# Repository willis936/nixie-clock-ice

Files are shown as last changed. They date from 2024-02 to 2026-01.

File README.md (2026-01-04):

# nixie-clock-ice

 Hardware and software source for a GPS nixie tube clock with delay correction.

Uses a PICO-iCE v3 FPGA + MCU module.

 - Raspberry Pi RP2040 processor
 - Lattice UltraPlus ICE40UP5K FPGA with 5.3k LUTs, 1Mb SPRAM, 120Kb DPRAM, 8 Multipliers

# Building

## Cloning

Clone with git CLI of the native OS (Windows if running WSL).
This avoids checkout conflicts.
Github desktop recursively inits submodules, which breaks on Windows due to path length limitations.

```
git clone https://github.com/willis936/nixie-clock-ice.git
```

Once cloned cd to `software/lib` and run these commands to initialize the submodules:

```
git -C pico-ice-sdk submodule update --init
git -C pico-sdk submodule update --init lib/tinyusb
```

Run these commands until the output stops changing.  Running them once is likely not sufficient.

See the "Using the SDK" section of the pico iCE "Getting Started" page.

https://pico-ice.tinyvision.ai/md_getting_started.html

## MCU

Follow the pico ice Getting Started section.

Using Ubuntu WSL the apt version of cmake is currently not high enough.

Install an appropriate version like this:

https://www.linuxcapable.com/how-to-install-cmake-on-ubuntu-linux/

```
sudo apt update && sudo apt install build-essential checkinstall zlib1g-dev libssl-dev g++ gdb make ninja-build rsync zip gcc-arm-none-eabi
cd /usr/local/src
sudo wget https://github.com/Kitware/CMake/archive/refs/tags/v3.28.1.tar.gz
sudo tar -zxvf v3.28.1.tar.gz
sudo rm v3.28.1.tar.gz
cd CMake-3.28.1
sudo ./bootstrap
sudo make
sudo make install
```

For MacOS with homebrew installed:
```
brew install cmake gcc-arm-embedded zlib gdb make rsync zip
```

## FPGA

Make sure python 3.7+ is installed on WSL.

You may need to install pyenv, remove prior pip installations, and re-bootstrap.

https://gist.github.com/monkut/35c2ef098b871144b49f3f9979032cee

https://pip.pypa.io/en/stable/installation/

Install apio and oss CAD suite.

You may need to restart WSL in between the pip installation of the package and the package installation (last two commands).

```
sudo apt update && sudo apt install python3-pip yosys
pip install -U apio
apio install -a
```

For MacOS:
```
brew install yosys
pip3 install -U apio
```

Test project using the APIO guide here:

https://pico-ice.tinyvision.ai/md_programming_the_fpga.html

Use UF2 on WSL to convert the bin to UF2 then copy over CURRENT.UF2 on mounted USB drive pico ice.

https://github.com/tinyvision-ai-inc/uf2-utils/

```
cd /usr/local/src
sudo git clone https://github.com/tinyvision-ai-inc/uf2-utils.git
cd uf2-utils && sudo make install
```

# Enclosure development

If you want to modify the FreeCAD FCStd files you should configure zippey (located in `software/lib`) with these commands from git bash (Windows) or shell (linux) with the repo as pwd:

```
git config filter.zippey.smudge "$PWD/software/lib/zippey.py d"
git config filter.zippey.clean "$PWD/software/lib/zippey.py e"
```

Note that you need python 3 installed and added to path as `python` for the .FCStd files to properly compress on clone.

The enclosure was developed in FreeCAD 0.21.2 + Assembly3.  The Assembly3 plugin is needed to load the .FCStd file and modify the enclosure.

The enclosure starting point was generated by Protocase's template generator.

# Requirements

1. Display the time with 1 microsecond accuracy.
2. Display the time with 1 second precision.
3. Use nixie tubes to display the time.
4. Do not require or allow the user to manually set the time.
5. Display the time within 30 seconds of power on.
6. Use a single power entry.
7. Use a single radio receiver to establish local timebase.
8. Have a user-selectable mode for Daylight Savings Time (DST) checking.
9. Use longitude to estimate DST date range.
10. Have a user-selectable mode to force DST offset on (off when both this and DST check mode are off).
11. Use longitude to estimate timezone.
12. Have a user-selectable timezone offset.
13. Be able to use software to control nixie tube brightness.
14. Use an ambient light detector to automatically adjust nixie tube brightness.
15. Have a user-selectable manual brightness mode.
16. Use a potentiometer to set the brightness in manual brightness mode.
17. Run a nixie tube anti-poisoning routine once a day (cycle through all digits at high brightness for a minute).
18. Have a user-selectable mode to enable daily anti-poisoning routine
19. Have a user-selectable mode to force anti-poisoning routine on indefinitely.
20. Have a user-selectable 12-hour / 24-hour display mode.
21. Use a nixie tube decimal point to indicate AM/PM in 12-hour display mode.
22. Use a nixie tube decimal point to indicate that the radio receiver is locked.

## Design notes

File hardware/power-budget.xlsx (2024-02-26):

load | 5V (mA) | 3.3V (mA) | HV (mA) | 3.3V standby (mA)
nixies | 1680 |  | 33.6
RP2040 | 100 | 100
ice 40 UP5K | 50 | 50 |  | 0.25
MCP23008 | 1 | 1
LTR-329ALS-01 | 1.25 | 1.25
PX1125T | 100 | 100 |  | 0.54
ADC0820 | 7.5
Total | 1939.75 | 252.25 | 33.6 | 0.79

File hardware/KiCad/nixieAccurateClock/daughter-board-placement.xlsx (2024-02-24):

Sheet: clock
width | 152.4
edge | 2
width-working | 148.4
width-unit | 16
N-unit | 6
N-gaps | 5
width-spacing-total | 52.4
width-spacing-average | 10.48
N-gap-large | 2
width-gap-large | 13
width-gap-small | 8.8
origin | 15.875
width-mount | 4
offset-right | 6.08
offset-left | -5.92
clock | X
N1 | 158.195
N2 | 133.395
N3 | 104.395
N4 | 79.595
N5 | 50.595
N6 | 25.795

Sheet: precise
width | 152.4
edge | 2
width-working | 148.4
width-unit | 16
N-unit | 6
N-gaps | 5
width-spacing-total | 52.4
width-spacing-average | 10.48
N-gap-large | 1
width-gap-large | 19
width-gap-small | 8.35
width-mount | 4
offset-right | 11.25
offset-left | -0.75
precise | X
N1 | 137.15
N2 | 112.8
N3 | 88.45
N4 | 53.45
N5 | 29.1
N6 | 4.75

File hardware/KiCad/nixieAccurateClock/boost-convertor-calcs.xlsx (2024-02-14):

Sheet: HV supply
Calcs from Art of Electronics - 3rd Edition, Section 9.6.6.a Boost convertor equations (continuous-conduction mode)
Bourns SRR1280-100M
 | nominal |  | min | max
Iout | 0.5368421053 | A | 0.4421052632 | 1.414736842
Vin | 4.75 | V | 4.75 | 4.75
f | 100000 | Hz | 100000 | 100000
T | 1e-05 | s | 1e-05 | 1e-05
L | 1e-05 | H | 1e-05 | 1e-05
Iin | 0.002659279778 | A | 0.002659279778 | 0.005956786704
Iin-delta | 4.219117647 | A | 4.105357143 | 4.29875
Vout | 42.5 | V | 35 | 50
D(uty cycle) | 88.82% |  | 86.43% | 90.50%
Iout(min) | 0.2357742215 | A | 0.2785778061 | 0.204190625
Ic(out)-delta | 4.8033241 | A | 3.257617729 | 14.89196676
IL(pk) | 6.912882923 | A | 5.3102963 | 17.04134176
Lmin | 4.391872753e-06 | H | 6.301164662e-06 | 1.443311709e-06

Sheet: Nixie limiting
Vdrop | 145 | V
R | 27000 | Ohm
Imin | -0.0001851851852 | A
Inom | 0.0009259259259 | A
Imax | 0.002037037037 | A
Vres-min | -5 | V
Vres-nom | 25 | V
Vres-max | 55 | V
Pres-min | 0.0009259259259 | W
Pres-nom | 0.02314814815 | W
Pres-max | 0.112037037 | W

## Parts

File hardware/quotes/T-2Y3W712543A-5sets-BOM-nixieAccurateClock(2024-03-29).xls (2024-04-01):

PCBWay Bom Quotation, Product No.:T-2Y3W712543A
Item # | *Designator | *Qty | Manufacturer | *Mfg Part # | Description / Value | *Package/Footprint | Mounting Type | Your Instructions / Notes | *Unit Price(5 sets) | *Total | *Delivery Time | *Actual Purchase Mfg Part # | *PCBWay Note | Customer Reply | PCBWay Update
1 | D1,D2,D3,D5,D6 | 5 |  | SM4004 | SM4004『 』https://www.mouser.com/ProductDetail/Diotec-Semiconductor/SM4004?qs=OlC7AqGiEDkXkiBPoivHAA%3D%3D | Diode_SMD:D_MELF | Surface Mount | http://cdn-reichelt.de/documents/datenblatt/A400/SMD1N400%23DIO.pdf『 』https://www.digikey.com/en/products/detail/diotec-semiconductor/SM4004/13155357 | $0.274 | $6.850 | 7-10 Workdays
2 | J11,J12,J13,J14,J15,J16 | 6 |  | SSM-105-L-DV | ~『 』https://www.mouser.com/ProductDetail/Samtec/SSM-105-L-DV?qs=92ilVni64gwpNieSff7mAQ%3D%3D | 00_lib:IN-14 daughter board | Surface Mount | http://suddendocs.samtec.com/catalog_english/ssm_sm.pdf『 』https://www.digikey.com/en/products/detail/samtec-inc/SSM-105-L-DV/1106226 | $3.176 | $95.280 | 7-10 Workdays
3 | U1 | 1 |  | MCP23008-E/SO | MCP23008-xSO『 』https://www.mouser.com/ProductDetail/Microchip-Technology/MCP23008-E-SO?qs=Sez7gRs8XSWum74ZwQXTLw%3D%3D | Package_SO:SOIC-18W_7.5x11.6mm_P1.27mm | Surface Mount | http://ww1.microchip.com/downloads/en/DeviceDoc/MCP23008-MCP23S08-Data-Sheet-20001919F.pdf『 』https://www.digikey.com/en/products/detail/microchip-technology/MCP23008-E-SO/735952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 | $1.790 | $8.950 | 7-10 Workdays
4 | J17 | 1 |  | M20-7920542R | Conn_02x05_Odd_Even『 』https://www.mouser.com/ProductDetail/Harwin/M20-7920542R?qs=k41KVqW3ymqj80AqJ%2FxUlA%3D%3D | 00_lib:M207920542R | Surface Mount, Right Angle | https://cdn.harwin.com/pdfs/M20-792R.pdf『 』https://www.digikey.com/en/products/detail/harwin-inc/M20-7920542R/6559290 | $1.308 | $6.540
5 | C1,C2,C3,C9,C10,C11,C12,C13,C14,C15,C16,C17 | 12 |  | CL10B104KB8NNWC | 0.1u『 』https://www.mouser.com/ProductDetail/Samsung-Electro-Mechanics/CL10A105KA8NNNC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 | Capacitor_SMD:C_0603_1608Metric | Surface Mount, MLCC | https://mm.digikey.com/Volume0/opasdata/d220001/medias/docus/609/CL10A105KA8NNNC_Spec.pdf『 』https://www.digikey.com/en/products/detail/samsung-electro-mechanics/CL10A105KA8NNNC/3886760 | $0.024 | $1.440
6 | C8 | 1 |  | CL10A105KA8NNNC | 1u『 』https://www.mouser.com/ProductDetail/Samsung-Electro-Mechanics/CL10A105KA8NNNC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 | Capacitor_SMD:C_0603_1608Metric | Surface Mount, MLCC | https://mm.digikey.com/Volume0/opasdata/d220001/medias/docus/609/CL10A105KA8NNNC_Spec.pdf『 』https://www.digikey.com/en/products/detail/samsung-electro-mechanics/CL10A105KA8NNNC/3886760 | $0.050 | $0.250
7 | U3 | 1 |  |  | PX1125T『 』N/A | 00_lib:PX1125T |  | https://navspark.mybigcommerce.com/content/PX1125T_DS.pdf『 』N/A | $48.000 | $240.000 |  | PX1125T | Our quotation with import taxes and shipping freight included. | Navspark PX1125T https://navspark.mybigcommerce.com/px1125t-l1-l5-gnss-timing/ https://navspark.mybigcommerce.com/content/PX1125T_DS.pdf
8 | U2 | 1 |  | LTR-329ALS-01 | LTR-329ALS-01『 』https://www.mouser.com/ProductDetail/Lite-On/LTR-329ALS-01?qs=Ml%2FaxAEbwm8eHg8LIDPUrw%3D%3D | 00_lib:LTR-329ALS-01_LTO |  | https://optoelectronics.liteon.com/upload/download/DS86-2014-0006/LTR-329ALS-01_DS_V1.pdf『 』https://www.digikey.com/en/products/detail/liteon/LTR-329ALS-01/4847334 | $0.403 | $2.015
9 | J8 | 1 |  | 132289 | Conn_Coaxial『 』https://www.mouser.com/ProductDetail/Amphenol-RF/132289?qs=nhkRCwpTkeb9ti20UXE5Cg%3D%3D | 00_lib:SMA_Amphenol_132289_EdgeMount | Board Edge, End Launch; Panel Mount | https://s3-us-west-2.amazonaws.com/catsy.582/132289.pdf『 』https://www.digikey.com/en/products/detail/amphenol-rf/132289/1989875 | $7.587 | $37.935
10 | J4 | 1 |  | SSM-120-L-DV-A | pico iCE (A)『 』https://www.mouser.com/ProductDetail/Samtec/SSM-120-L-DV-A?qs=rU5fayqh%252BE2VZqLoNez%252BbA%3D%3D | 00_lib:pico iCE (A) | Surface Mount | https://suddendocs.samtec.com/catalog_english/ssm_sm.pdf『 』https://www.digikey.com/en/products/detail/samtec-inc/SSM-120-L-DV-A/7861007 | $8.846 | $44.230 | 7-10 Workdays
11 | J5 | 1 |  | SSM-120-L-DV-A | pico iCE (B)『 』https://www.mouser.com/ProductDetail/Samtec/SSM-120-L-DV-A?qs=rU5fayqh%252BE2VZqLoNez%252BbA%3D%3D | 00_lib:pico iCE (B) | Surface Mount | https://suddendocs.samtec.com/catalog_english/ssm_sm.pdf『 』https://www.digikey.com/en/products/detail/samtec-inc/SSM-120-L-DV-A/7861007 | $8.846 | $44.230 | 7-10 Workdays
12 | J1,J2,J3,J6,J7,J9,J10 | 7 |  | TSM-102-01-L-SV | Conn_01x02_Pin『 』https://www.mouser.com/ProductDetail/Samtec/TSM-102-01-L-SV?qs=FESYatJ8odJ%252BIhPvKBkuBA%3D%3D | Connector_PinHeader_2.54mm:PinHeader_1x02_P2.54mm_Vertical_SMD_Pin1Left | Surface Mount | https://suddendocs.samtec.com/catalog_english/tsm.pdf『 』https://www.digikey.com/en/products/detail/samtec-inc/TSM-102-01-L-SV/2685520 | $0.382 | $13.370
13 | F1 | 1 |  | 0ZCJ0100FF2E | 1A『 』https://www.mouser.com/ProductDetail/Bel-Fuse/0ZCJ0100FF2E?qs=SRYZG9HaIQ16trCtSE8WyA%3D%3D | Fuse:Fuse_1206_3216Metric | Surface Mount | https://www.belfuse.com/resources/datasheets/circuitprotection/ds-cp-0zcj-series.pdf『 』https://www.digikey.com/en/products/detail/bel-fuse-inc/0ZCJ0100FF2E/4156136 | $0.382 | $1.910
14 | RV1 | 1 |  | 3269X-1-104GLF | 100k『 』https://www.mouser.com/ProductDetail/Bourns/3269X-1-104GLF?qs=Rk6YzfsJF02hTa5cSpJqSw%3D%3D | Potentiometer_SMD:Potentiometer_Bourns_3269X_Horizontal | Surface Mount | https://www.bourns.com/docs/Product-Datasheets/3269.pdf『 』https://www.digikey.com/en/products/detail/bourns-inc/3269X-1-104GLF/2535630 | $5.064 | $25.320 | 7-10 Workdays
15 | L1 | 1 |  | SRR1280-100M | 10u『 』https://www.mouser.com/ProductDetail/Bourns/SRR1280-100M?qs=brMhP%2FMjUfe%2FtbNTKcGHiQ%3D%3D | 00_lib:IND_BOURNS_SRR1280 | Surface Mount | https://www.bourns.com/docs/Product-Datasheets/SRR1280.pdf『 』https://www.digikey.com/en/products/detail/bourns-inc/SRR1280-100M/1969992 | $0.910 | $4.550
16 | SW1 | 1 |  | 219-8MST | SW_DIP_x08『 』https://www.mouser.com/ProductDetail/CTS-Electronic-Components/219-8MST?qs=qNzHFtQhdJ%252B8jOs%2FDCRqeg%3D%3D | Button_Switch_SMD:SW_DIP_SPSTx08_Slide_6.7x21.88mm_W8.61mm_P2.54mm_LowProfile | Surface Mount | https://www.ctscorp.com/wp-content/uploads/219.pdf『 』https://www.digikey.com/en/products/detail/cts-electrocomponents/219-8MST/223209 | $1.006 | $5.030
17 | D4 | 1 |  | 1SMB5956B-13 | 1SMB5956B-13『 』https://www.mouser.com/ProductDetail/Diodes-Incorporated/1SMB5956B-13?qs=uwKJARvjadOTUcHkJGZGig%3D%3D | Diode_SMD:D_SMB | Surface Mount | https://www.diodes.com/assets/Datasheets/ds32125.pdf『 』https://www.digikey.com/en/products/detail/diodes-incorporated/1SMB5956B-13/5054209 | $0.285 | $1.425
18 | BT1 | 1 | Keystone Electronics | 3002 | Battery_Cell『 』https://www.mouser.com/ProductDetail/Keystone-Electronics/3002?qs=Mn60vILZNNZWJpgHXc3g8Q%3D%3D | Battery:BatteryHolder_Keystone_3002_1x2032 |  | https://www.keyelco.com/userAssets/file/M65p9.pdf『 』https://www.digikey.com/en/products/detail/keystone-electronics/3002/227444 | $0.532 | $2.660 | 7-10 Workdays
19 | TP1,TP2,TP3,TP4,TP5,TP6,TP7,TP8,TP9 | 9 |  | 5019 | TestPoint『 』https://www.mouser.com/ProductDetail/Keystone-Electronics/5019?qs=wOxb8XianXjjCAsb90Ilzw%3D%3D | 00_lib:TestPoint_Keystone_5019_Minature |  | https://www.mouser.com/datasheet/2/215/019-743690.pdf『 』https://www.digikey.com/en/products/detail/keystone-electronics/5019/3907343 | $0.362 | $16.290
20 | C4,C5,C6,C7 | 4 |  | UUX2G010MNL1GS | 1u『 』https://www.mouser.com/ProductDetail/Nichicon/UUX2G010MNL1GS?qs=aoAypCcaRa%2FXm3BGeiMtMQ%3D%3D | Capacitor_SMD:CP_Elec_8x10 | Surface Mount | https://www.nichicon.co.jp/english/series_items/catalog_pdf/e-uux.pdf『 』https://www.digikey.com/en/products/detail/nichicon/UUX2G010MNL1GS/3973996 | $0.491 | $9.820 | 7-10 Workdays
21 | Q1,Q2,Q3,Q4,Q5,Q6 | 6 |  | PZTA42-TP | PZTA42『 』https://www.mouser.com/ProductDetail/Diotec-Semiconductor/PZTA42?qs=OlC7AqGiEDlNqlN7791aVQ%3D%3D | Package_TO_SOT_SMD:SOT-223-3_TabPin2 | Surface Mount | https://www.onsemi.com/pub/Collateral/PZTA42T1-D.PDF『 』https://www.digikey.com/en/products/detail/micro-commercial-co/PZTA42-TP/10054674 | $0.443 | $13.290 | 7-10 Workdays
22 | R5,R6,R7,R8 | 4 |  | CSRN2010FKR500 | 0.5『 』https://www.mouser.com/ProductDetail/SEI-Stackpole/CSRN2010FKR500?qs=FESYatJ8odLqZqv0DvLABQ%3D%3D | Resistor_SMD:R_2010_5025Metric |  | https://www.seielect.com/catalog/sei-csr_csrn.pdf『 』https://www.digikey.com/en/products/detail/stackpole-electronics-inc/CSRN2010FKR500/1742702 | $0.334 | $6.680 | 7-10 Workdays
23 | R3 | 1 |  | RMCF0603FT10M0 | 10M『 』https://www.mouser.com/ProductDetail/SEI-Stackpole/RMCF0603FT10M0?qs=FESYatJ8odIf0bWpBT4vKw%3D%3D | Resistor_SMD:R_0603_1608Metric |  | https://www.seielect.com/catalog/sei-rmcf_rmcp.pdf『 』https://www.digikey.com/en/products/detail/stackpole-electronics-inc/RMCF0603FT10M0/1761206 | $0.046 | $0.230
24 | R9,R12 | 2 |  | RMCF0603FT1M00 | 1M『 』https://www.mouser.com/ProductDetail/SEI-Stackpole/RMCF0603FT1M00?qs=FESYatJ8odJNClY0wUC1cg%3D%3D | Resistor_SMD:R_0603_1608Metric |  | https://www.seielect.com/catalog/sei-rmcf_rmcp.pdf『 』https://www.digikey.com/en/products/detail/stackpole-electronics-inc/RMCF0603FT1M00/1761036 | $0.046 | $0.460
25 | R10 | 1 |  | 352010KJT | 10k『 』https://www.mouser.com/ProductDetail/TE-Connectivity-Holsworthy/352010KJT?qs=DDevMFOh4ssnVH2d0oCe7g%3D%3D | Resistor_SMD:R_2512_6332Metric |  | https://www.te.com/commerce/DocumentDelivery/DDEController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『 』https://www.digikey.com/en/products/detail/te-connectivity-passive-product/352010KJT/2364839 | $0.427 | $2.135 | 7-10 Workdays
26 | U6 | 1 |  | ADC0820BCWMX/NOPB | ADC0820BCWMX『 』https://www.mouser.com/ProductDetail/Texas-Instruments/ADC0820BCWMX-NOPB?qs=7X5t%252BdzoRHBt6RLxd4fqnA%3D%3D | Package_SO:SOIC-20W_7.5x12.8mm_P1.27mm | Surface Mount | https://www.ti.com/lit/ds/symlink/adc0820-n.pdf『 』https://www.digikey.com/en/products/detail/texas-instruments/ADC0820BCWMX-NOPB/366281 | $7.740 | $38.700 | 7-10 Workdays
27 | U4,U5,U7,U8 | 4 |  | TXU0104PWR | ~『 』https://www.mouser.com/ProductDetail/Texas-Instruments/TXU0104PWR?qs=QNEnbhJQKvYcSGbLlthvAQ%3D%3D | Package_SO:TSSOP-14_4.4x5mm_P0.65mm | Surface Mount | https://www.ti.com/lit/ds/symlink/txu0104.pdf『 』https://www.digikey.com/en/products/detail/texas-instruments/TXU0104PWR/14641439 | $0.926 | $18.520
28 | R1,R2 | 2 |  | RC0603FR-071KL | 1k『 』https://www.mouser.com/ProductDetail/YAGEO/RC0603FR-071KL?qs=VU8sRB4EgwApHsk4rF%2F3zg%3D%3D | Resistor_SMD:R_0603_1608Metric |  | https://www.yageo.com/upload/media/product/products/datasheet/rchip/PYu-RC_Group_51_RoHS_L_12.pdf『 』https://www.digikey.com/en/products/detail/yageo/RC0603FR-071KL/726843 | $0.021 | $0.210
29 | R4,R11 | 2 |  | RC0603JR-07100KL | 100k『 』https://www.mouser.com/ProductDetail/YAGEO/RC0603JR-07100KL?qs=2cAdsCoAWRG9Rhqklpdeqg%3D%3D | Resistor_SMD:R_0603_1608Metric |  | https://www.yageo.com/upload/media/product/products/datasheet/rchip/PYu-RC_Group_51_RoHS_L_12.pdf『 』https://www.digikey.com/en/products/detail/yageo/RC0603JR-07100KL/726698 | $0.021 | $0.210
30 | R13 | 1 |  | RC0603FR-0747KL | 47k『 』https://www.mouser.com/ProductDetail/YAGEO/RC0603FR-0747KL?qs=gt6vzsuosg3jXzmCiDCCdg%3D%3D | Resistor_SMD:R_0603_1608Metric |  | https://www.yageo.com/upload/media/product/products/datasheet/rchip/PYu-RC_Group_51_RoHS_L_12.pdf『 』https://www.digikey.com/en/products/detail/yageo/RC0603FR-0747KL/727253 | $0.042 | $0.210
31 |  | 0 |  |  |  |  |  |  |  |  |  |  | [DNP不要贴]; | DNP
 |  |  |  |  |  |  |  |  | Component Cost | $648.74
 |  |  |  |  |  |  |  |  | Assembly Cost | $40.14
 |  |  |  |  |  |  |  |  | PCB Cost | $116.71
 |  |  |  |  |  |  |  |  | V0 Member 0% off | $0.00
 |  |  |  |  |  |  |  |  | All Total 5 Sets | $805.59
 |  |  |  |  |  |  |  |  | Build time | 25-28days

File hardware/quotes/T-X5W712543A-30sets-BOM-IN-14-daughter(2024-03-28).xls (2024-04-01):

PCBWay Bom Quotation, Product No.:T-X5W712543A
Item # | *Designator | *Qty | *Mfg Part # | Description / Value | *Package/Footprint | Mounting Type | Your Instructions / Notes | *Unit Price(30 sets) | *Total | *Delivery Time | *PCBWay Note | Customer Reply | PCBWay Update
1 | C1,C2 | 2 | CL10B104KB8NNWC | 0.1u | Capacitor_SMD:C_0603_1608Metric | Surface Mount, MLCC | https://mm.digikey.com/Volume0/opasdata/d220001/medias/docus/658/CL10B104KB8NNWC_Spec.pdf『 』https://www.digikey.com/en/products/detail/samsung-electro-mechanics/CL10B104KB8NNWC/3887593『 』https://www.mouser.com/ProductDetail/Samsung-Electro-Mechanics/CL10B104KB8NNWC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 | $0.024 | $1.440
2 | J1 | 1 | 15-91-6100 | Conn_02x05_Odd_Even | Connector_PinHeader_2.54mm:PinHeader_2x05_P2.54mm_Vertical_SMD |  | https://www.molex.com/content/dam/molex/molex-dot-com/products/automated/en-us/productspecificationpdf/713/71308/PS-71308-001.pdf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『 』https://www.digikey.com/en/products/detail/molex/0015916100/3124523『 』https://www.mouser.com/ProductDetail/Molex/15-91-6100?qs=5ADmCPbgZvxX3zRPE3%2FoVw%3D%3D | $2.496 | $74.880
3 | N1 | 1 | IN-14 | IN-14 | 00_lib:nixies-us-IN-14 |  | DNP『 』https://tubehobby.com/datasheets/in14.pdf『 』N/A『 』N/A |  |  |  | [DNP不要贴];
4 | R1 | 1 | RC1206JR-0727KL | 27k | Resistor_SMD:R_1206_3216Metric |  | https://www.yageo.com/upload/media/product/app/datasheet/rchip/pyu-rc_group_51_rohs_l.pdf『 』https://www.digikey.com/en/products/detail/yageo/RC1206JR-0727KL/729262『 』https://www.mouser.com/ProductDetail/YAGEO/RC1206JR-0727KL?qs=CteSnpDdeuBg3%2FC0aG6GFQ%3D%3D | $0.038 | $1.140
5 | U1 | 1 | HV509K6-G | HV509K6-G | Package_DFN_QFN:QFN-32-1EP_5x5mm_P0.5mm_EP3.3x3.3mm_ThermalVias | Surface Mount | https://ww1.microchip.com/downloads/en/DeviceDoc/hv509.pdf『 』https://www.digikey.com/en/products/detail/microchip-technology/HV509K6-G/4902492『 』https://www.mouser.com/ProductDetail/Microchip-Technology/HV509K6-G?qs=073BFnXyqnuDeexnfjhPaQ%3D%3D | $3.252 | $97.560 | 7-10 Workdays
 |  |  |  |  |  |  |  | Component Cost | $175.02
 |  |  |  |  |  |  |  | Assembly Cost | $88.00
 |  |  |  |  |  |  |  | PCB Cost | $94.55
 |  |  |  |  |  |  |  | V0 Member 0% off | $0.00
 |  |  |  |  |  |  |  | All Total 30 Sets | $357.57
 |  |  |  |  |  |  |  | Build time | 25-26days

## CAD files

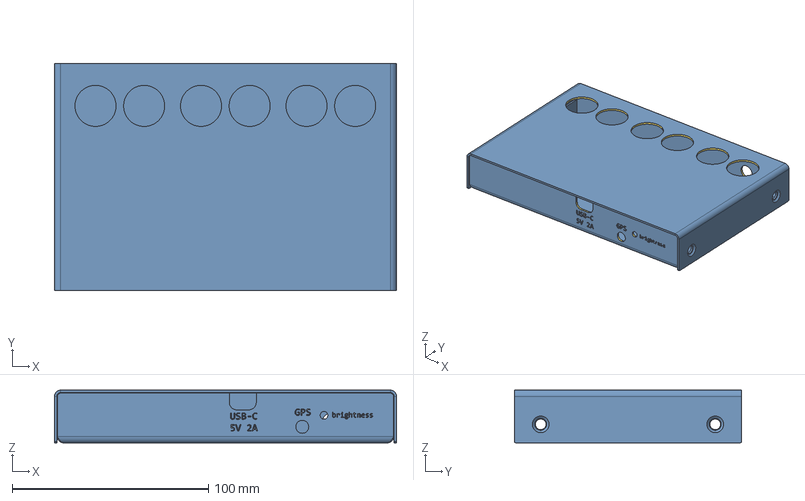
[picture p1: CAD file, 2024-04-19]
hardware/enclosure/nixieAccurateClock-B-enclosure-protocase-U-4.5-1-6.75-AssemblyU-Shape_Protocase.step
174.4 x 115.8 x 26.9 mm
brightness
GPS
5V 2A
USB-C
Base-Rear-Front-Bottom
Cover-Top

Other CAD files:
hardware/enclosure/test.FCStd

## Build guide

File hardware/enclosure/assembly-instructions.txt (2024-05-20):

1. Prepare main board.

1.1. Install 2x M2.5 5 mm M-F hex standoffs on the rear main board mounting holes with M2.5 hex nuts.

1.2. Remove plastic film from SW1 with tweezers.

1.3. Remove hex nut and spring from J8.

2. Install daughter boards.

2.1. pico ice

2.1.1. Solder 2x 2x20 0.1" pin headers to pico ice.

2.1.2. Install 4x 10 mm M2.5 F-F hex standoffs into pico ice receptacle mounting points with 4x M2.5 5 mm panhead screws on bottom of main board.

2.1.3. Push pico ice into receptacle.

2.1.4. Secure pico ice with 4x M2.5 5 mm panhead screws.

2.2. IN-14 nixie tube daughter boards

2.2.1. Solder 1x IN-14 nixie tube into each of 6x IN-14 nixie tube daughter boards.

2.2.2. Install 12x 10 mm M2.5 M-F hex standoffs into pico ice receptacle mounting points with 4x M2.5 5 mm panhead screws on bottom of main board.  The outer-most standoffs should be installed with M2.5 5 mm M-F standoffs instead of screws.

2.2.3. Install 2x M2.5 0.5 mm washers on top of each 10 mm M2.5 M-F hex standoff.

2.2.4. Push each IN-14 nixie tube daughter board into J11 - J16.

2.2.5. Secure IN-14 nixie tube daughter board with 12x M2.5 hex nuts.  These will likely need tweezers to cinch down.

3. Install PCBA into enclosure.

3.1. Push VCC 4342 clear snap-in lens into the 0.357" hole on the front of the enclosure.
https://www.digikey.com/en/products/detail/visual-communications-company-vcc/4342/60417

3.2. With the top cover hanging off of a table, lay daughter boards into top cover holes.

3.3. Slide main board SMA receptacle into the back cover hole.

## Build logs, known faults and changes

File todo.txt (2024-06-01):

[D] switch to single stage flyback topology
[D] simulate HV supply
[D] swap all TH for SM options
[D] swap daughter board footprints for proper pin socket BOM items
[D] refresh BOM
[D] switch to static level shifter, tie CS and RD low, direct connect WR, ignore INT

[ ] Second set of tubes on another board to the side for precision time (use a sense GPIO to increase the HV data width and OE rate)
[ ] IN-12 daughter board

https://github.com/azonenberg/pcb-checklist

[D] SW: blink LED
[D] SW: configure pinouts
[D] SW: get USB UF2 loading working (not possible for RP2040 firmware)
[D] SW: switch from C to C++
[D] SW: print to USB-serial
[D] SW: 1 kHz timed loop
[D] SW: dedicated thread for HV control
[D] SW: read in ADC value to trim PWM
[ ] SW: PWM drive for HV
[ ] SW: read in DIP switches
[ ] SW: read NMEA time
[ ] SW: HV509 shift register driver
[ ] SW: delay locked loop PPS to current sense comparator inputs
[ ] SW: experiment with adjusting brightness based on ambient light with voltage control
[ ] SW: new year's countdown with pulsing brightness and decimal point scan celebration
[ ] SW: show date once a minute with DIP switch setting

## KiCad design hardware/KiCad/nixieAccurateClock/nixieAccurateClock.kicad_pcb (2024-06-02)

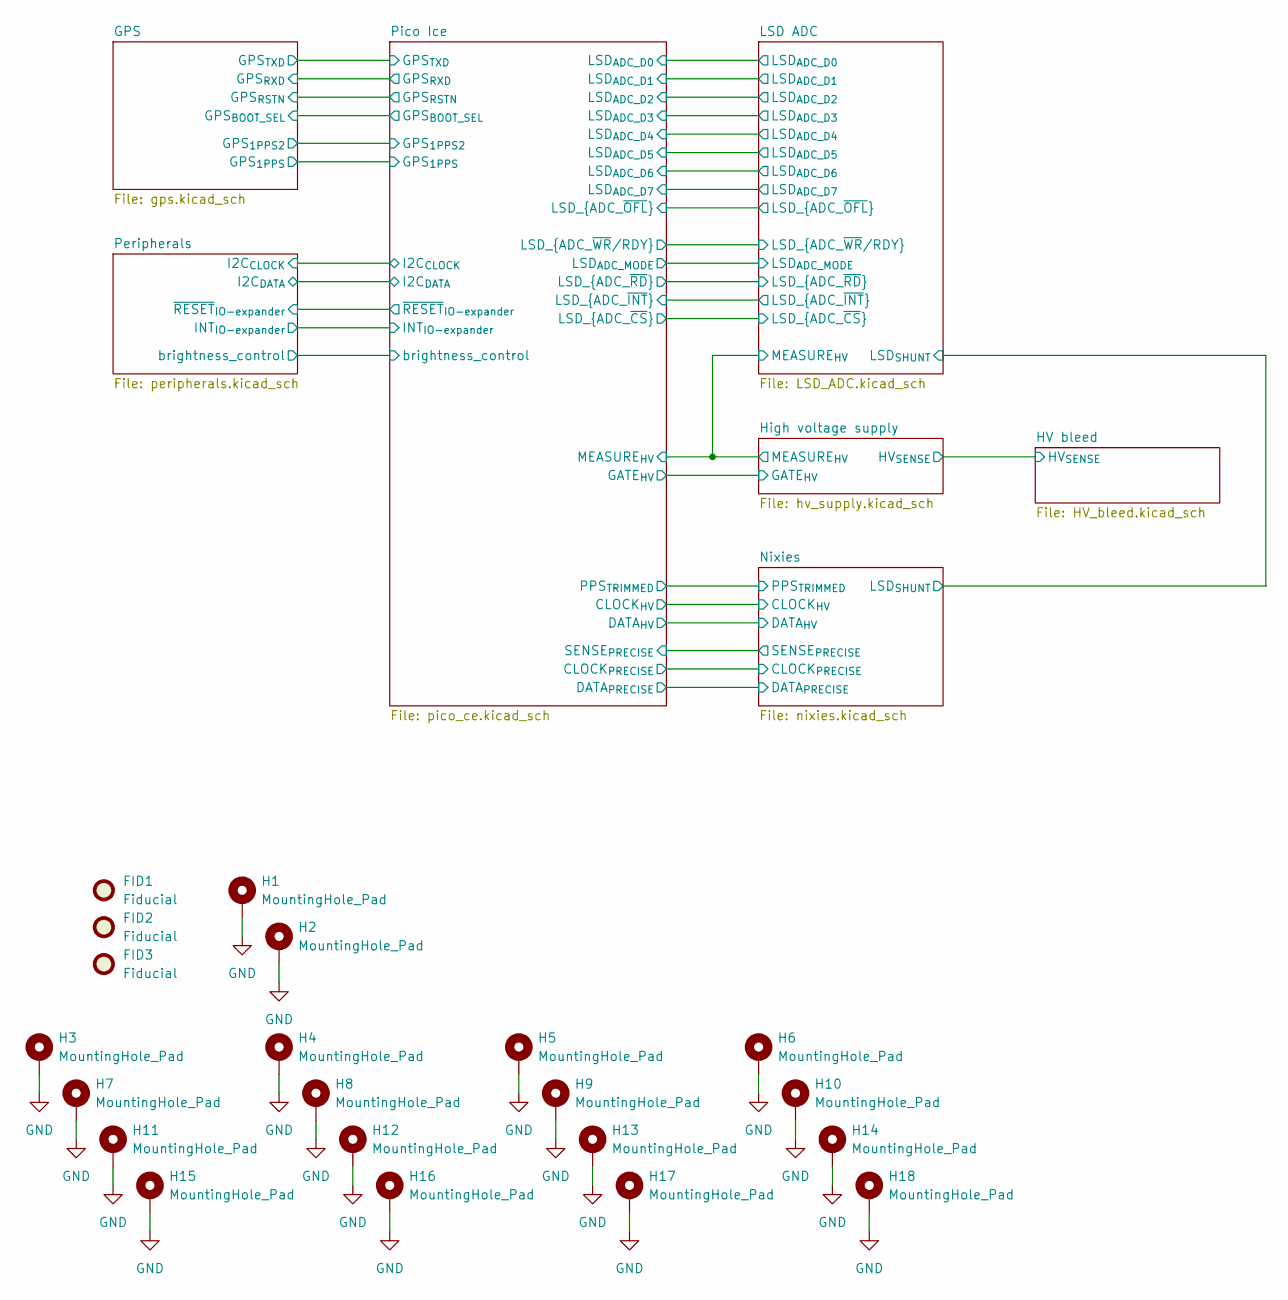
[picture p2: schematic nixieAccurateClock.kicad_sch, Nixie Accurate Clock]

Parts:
FID1, FID2, FID3: Fiducial; Fiducial_1mm_Mask3mm
H1, H2, H3, H4, H5, H6, H7, H8, H9, H10, H11, H12, H13, H14, H15, H16, H17, H18: MountingHole_Pad; MountingHole_2.7mm_M2.5_Pad_Via

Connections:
GND: H1.1, H2.1, H3.1, H4.1, H5.1, H6.1, H7.1, H8.1, H9.1, H10.1, H11.1, H12.1, H13.1, H14.1, H15.1, H16.1, H17.1, H18.1; also elsewhere on the board

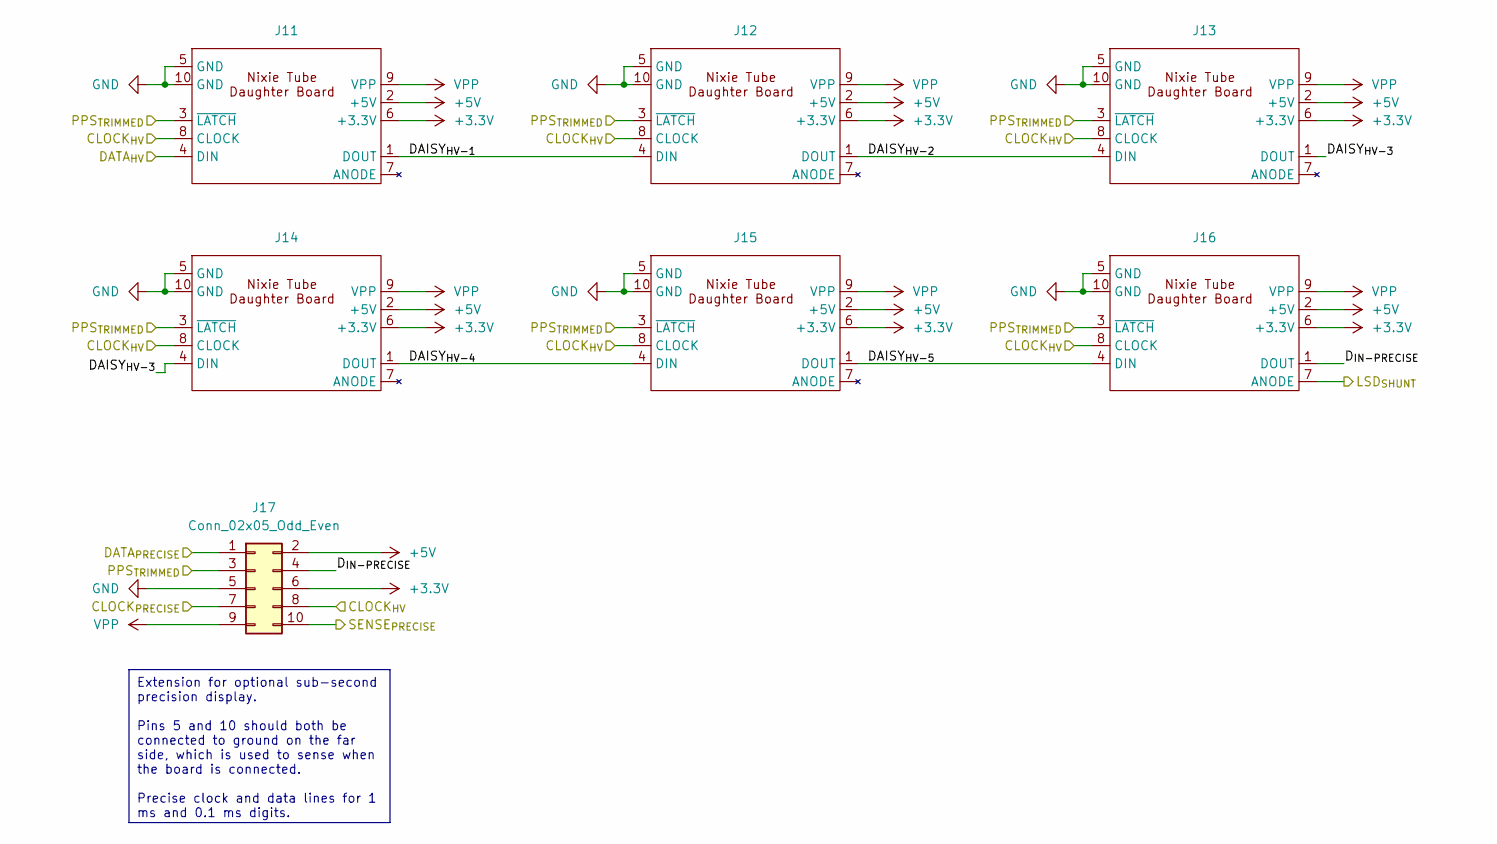
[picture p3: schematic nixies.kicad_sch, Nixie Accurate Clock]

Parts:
J11, J12, J13, J14, J15, J16: IN-14 daughter board
J17: Conn_02x05_Odd_Even; M207920542R

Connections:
+3.3V: J11.6 (+3.3V), J12.6 (+3.3V), J13.6 (+3.3V), J14.6 (+3.3V), J15.6 (+3.3V), J16.6 (+3.3V), J17.6; also elsewhere on the board
+5V: J11.2 (+5V), J12.2 (+5V), J13.2 (+5V), J14.2 (+5V), J15.2 (+5V), J16.2 (+5V), J17.2; also elsewhere on the board
/LSD ADC/LSD_{SHUNT}: J16.7 (ANODE); also elsewhere on the board
/Nixies/CLOCK_{HV}: J11.8 (CLOCK), J12.8 (CLOCK), J13.8 (CLOCK), J14.8 (CLOCK), J15.8 (CLOCK), J16.8 (CLOCK), J17.8; also elsewhere on the board
/Nixies/CLOCK_{PRECISE}: J17.7; also elsewhere on the board
/Nixies/DAISY_{HV-1}: J11.1 (DOUT), J12.4 (DIN)
/Nixies/DAISY_{HV-2}: J12.1 (DOUT), J13.4 (DIN)
/Nixies/DAISY_{HV-3}: J13.1 (DOUT), J14.4 (DIN)
/Nixies/DAISY_{HV-4}: J14.1 (DOUT), J15.4 (DIN)
/Nixies/DAISY_{HV-5}: J15.1 (DOUT), J16.4 (DIN)
/Nixies/DATA_{HV}: J11.4 (DIN); also elsewhere on the board
/Nixies/DATA_{PRECISE}: J17.1; also elsewhere on the board
/Nixies/D_{IN-PRECISE}: J16.1 (DOUT), J17.4
/Nixies/PPS_{TRIMMED}: J11.3 (~LATCH), J12.3 (~LATCH), J13.3 (~LATCH), J14.3 (~LATCH), J15.3 (~LATCH), J16.3 (~LATCH), J17.3; also elsewhere on the board
/Nixies/SENSE_{PRECISE}: J17.10; also elsewhere on the board
GND: J11.5 (GND), J11.10 (GND), J12.5 (GND), J12.10 (GND), J13.5 (GND), J13.10 (GND), J14.5 (GND), J14.10 (GND), J15.5 (GND), J15.10 (GND), J16.5 (GND), J16.10 (GND), J17.5; also elsewhere on the board
VPP: J11.9 (VPP), J12.9 (VPP), J13.9 (VPP), J14.9 (VPP), J15.9 (VPP), J16.9 (VPP), J17.9; also elsewhere on the board

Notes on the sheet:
Extension for optional sub-second precision display. Pins 5 and 10 should both be connected to ground on the far side, which is used to sense when the board is connected. Precise clock and data lines for 1 ms and 0.1 ms digits.

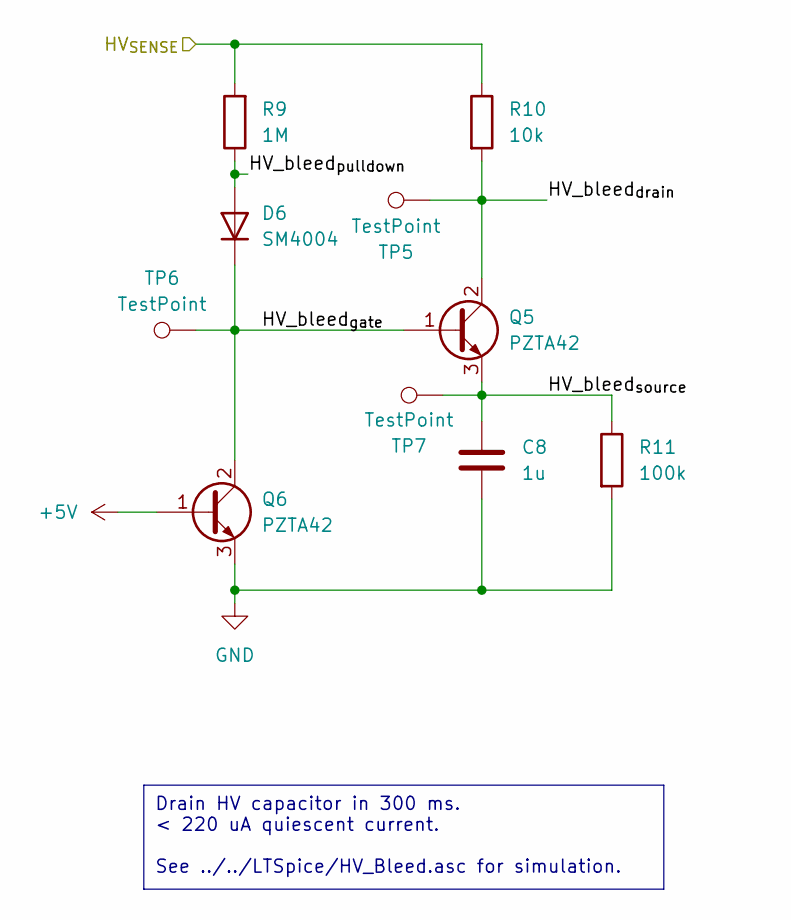
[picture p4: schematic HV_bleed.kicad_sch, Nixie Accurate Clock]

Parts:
C8: 1u; C_0603_1608Metric
D6: SM4004; D_MELF
Q5, Q6: PZTA42; SOT-223-3_TabPin2
R9: 1M; R_0603_1608Metric
R10: 10k; R_2512_6332Metric
R11: 100k; R_0603_1608Metric
TP5, TP6, TP7: TestPoint; TestPoint_Keystone_5019_Minature

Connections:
+5V: Q6.1 (B); also elsewhere on the board
/HV bleed/HV_bleed_{drain}: Q5.2 (C), R10.2, TP5.1
/HV bleed/HV_bleed_{gate}: D6.1 (K), Q5.1 (B), Q6.2 (C), TP6.1
/HV bleed/HV_bleed_{pulldown}: D6.2 (A), R9.1
/HV bleed/HV_bleed_{source}: C8.1, Q5.3 (E), R11.1, TP7.1
/HV bleed/HV_{SENSE}: R9.2, R10.1; also elsewhere on the board
GND: C8.2, Q6.3 (E), R11.2; also elsewhere on the board

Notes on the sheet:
Drain HV capacitor in 300 ms. < 220 uA quiescent current. See ../../LTSpice/HV_Bleed.asc for simulation.

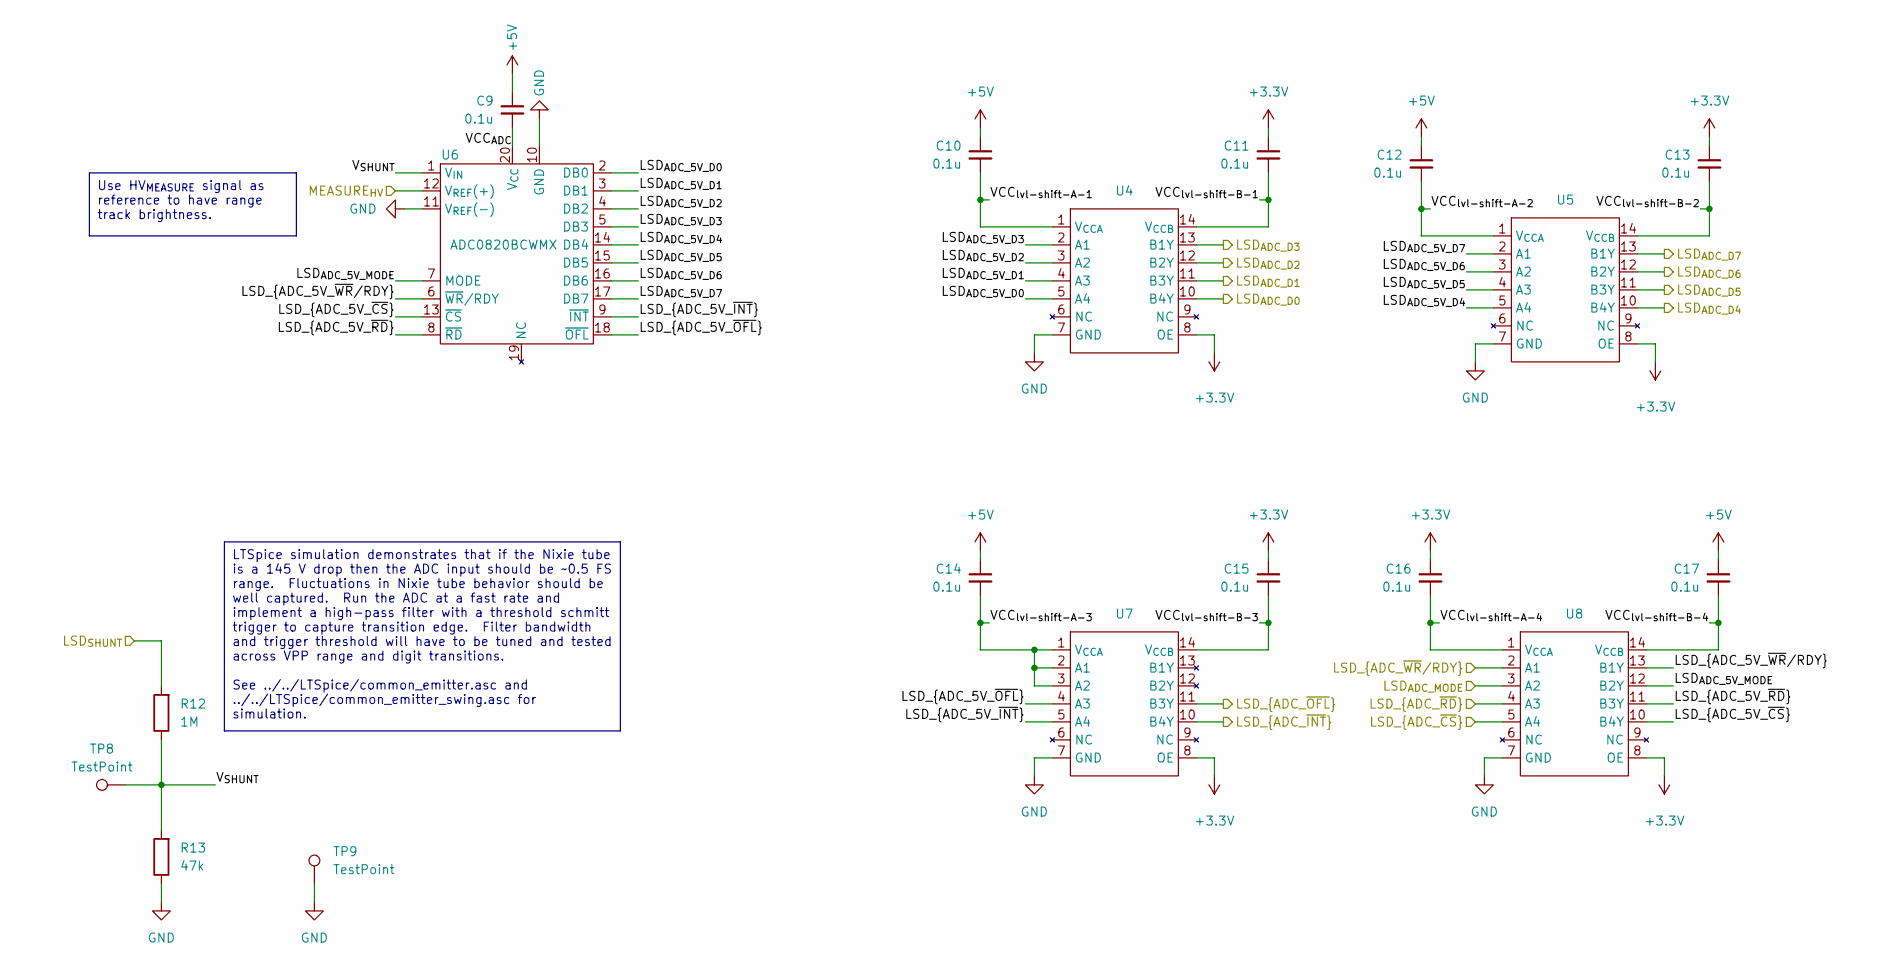
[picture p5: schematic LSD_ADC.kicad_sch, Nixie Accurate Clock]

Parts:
C9, C10, C11, C12, C13, C14, C15, C16, C17: 0.1u; C_0603_1608Metric
R12: 1M; R_0603_1608Metric
R13: 47k; R_0603_1608Metric
TP8, TP9: TestPoint; TestPoint_Keystone_5019_Minature
U4, U5, U7, U8: TSSOP-14_4.4x5mm_P0.65mm
U6: ADC0820BCWMX; SOIC-20W_7.5x12.8mm_P1.27mm

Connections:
+3.3V: C11.1, C13.1, C15.1, C16.1, U4.8 (OE), U5.8 (OE), U7.8 (OE), U8.8 (OE); also elsewhere on the board
+5V: C9.1, C10.1, C12.1, C14.1, C17.1; also elsewhere on the board
/High voltage supply/MEASURE_{HV}: U6.12 (V_{REF}(+)); also elsewhere on the board
/LSD ADC/LSD_{ADC_5V_D0}: U4.5 (A4), U6.2 (DB0)
/LSD ADC/LSD_{ADC_5V_D1}: U4.4 (A3), U6.3 (DB1)
/LSD ADC/LSD_{ADC_5V_D2}: U4.3 (A2), U6.4 (DB2)
/LSD ADC/LSD_{ADC_5V_D3}: U4.2 (A1), U6.5 (DB3)
/LSD ADC/LSD_{ADC_5V_D4}: U5.5 (A4), U6.14 (DB4)
/LSD ADC/LSD_{ADC_5V_D5}: U5.4 (A3), U6.15 (DB5)
/LSD ADC/LSD_{ADC_5V_D6}: U5.3 (A2), U6.16 (DB6)
/LSD ADC/LSD_{ADC_5V_D7}: U5.2 (A1), U6.17 (DB7)
/LSD ADC/LSD_{ADC_5V_MODE}: U6.7 (MODE), U8.12 (B2Y)
/LSD ADC/LSD_{ADC_5V_~CS}: U6.13 (~CS), U8.10 (B4Y)
/LSD ADC/LSD_{ADC_5V_~INT}: U6.9 (~INT), U7.5 (A4)
/LSD ADC/LSD_{ADC_5V_~OFL}: U6.18 (~OFL), U7.4 (A3)
/LSD ADC/LSD_{ADC_5V_~RD}: U6.8 (~RD), U8.11 (B3Y)
/LSD ADC/LSD_{ADC_5V_~WR/RDY}: U6.6 (~WR/RDY), U8.13 (B1Y)
/LSD ADC/LSD_{ADC_D0}: U4.10 (B4Y); also elsewhere on the board
/LSD ADC/LSD_{ADC_D1}: U4.11 (B3Y); also elsewhere on the board
/LSD ADC/LSD_{ADC_D2}: U4.12 (B2Y); also elsewhere on the board
/LSD ADC/LSD_{ADC_D3}: U4.13 (B1Y); also elsewhere on the board
/LSD ADC/LSD_{ADC_D4}: U5.10 (B4Y); also elsewhere on the board
/LSD ADC/LSD_{ADC_D5}: U5.11 (B3Y); also elsewhere on the board
/LSD ADC/LSD_{ADC_D6}: U5.12 (B2Y); also elsewhere on the board
/LSD ADC/LSD_{ADC_D7}: U5.13 (B1Y); also elsewhere on the board
/LSD ADC/LSD_{ADC_MODE}: U8.3 (A2); also elsewhere on the board
/LSD ADC/LSD_{ADC_~CS}: U8.5 (A4); also elsewhere on the board
/LSD ADC/LSD_{ADC_~INT}: U7.10 (B4Y); also elsewhere on the board
/LSD ADC/LSD_{ADC_~OFL}: U7.11 (B3Y); also elsewhere on the board
/LSD ADC/LSD_{ADC_~RD}: U8.4 (A3); also elsewhere on the board
/LSD ADC/LSD_{ADC_~WR/RDY}: U8.2 (A1); also elsewhere on the board
/LSD ADC/LSD_{SHUNT}: R12.2; also elsewhere on the board
/LSD ADC/VCC_{ADC}: C9.2, U6.20 (V_{CC})
/LSD ADC/VCC_{lvl-shift-A-1}: C10.2, U4.1 (V_{CCA})
/LSD ADC/VCC_{lvl-shift-A-2}: C12.2, U5.1 (V_{CCA})
/LSD ADC/VCC_{lvl-shift-A-3}: C14.2, U7.1 (V_{CCA}), U7.2 (A1), U7.3 (A2)
/LSD ADC/VCC_{lvl-shift-A-4}: C16.2, U8.1 (V_{CCA})
/LSD ADC/VCC_{lvl-shift-B-1}: C11.2, U4.14 (V_{CCB})
/LSD ADC/VCC_{lvl-shift-B-2}: C13.2, U5.14 (V_{CCB})
/LSD ADC/VCC_{lvl-shift-B-3}: C15.2, U7.14 (V_{CCB})
/LSD ADC/VCC_{lvl-shift-B-4}: C17.2, U8.14 (V_{CCB})
/LSD ADC/V_{SHUNT}: R12.1, R13.2, TP8.1, U6.1 (V_{IN})
GND: R13.1, TP9.1, U4.7 (GND), U5.7 (GND), U6.10 (GND), U6.11 (V_{REF}(-)), U7.7 (GND), U8.7 (GND); also elsewhere on the board

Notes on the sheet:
Use HV_{MEASURE} signal as reference to have range track brightness.
LTSpice simulation demonstrates that if the Nixie tube is a 145 V drop then the ADC input should be ~0.5 FS range. Fluctuations in Nixie tube behavior should be well captured. Run the ADC at a fast rate and implement a high-pass filter with a threshold schmitt trigger to capture transition edge. Fi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

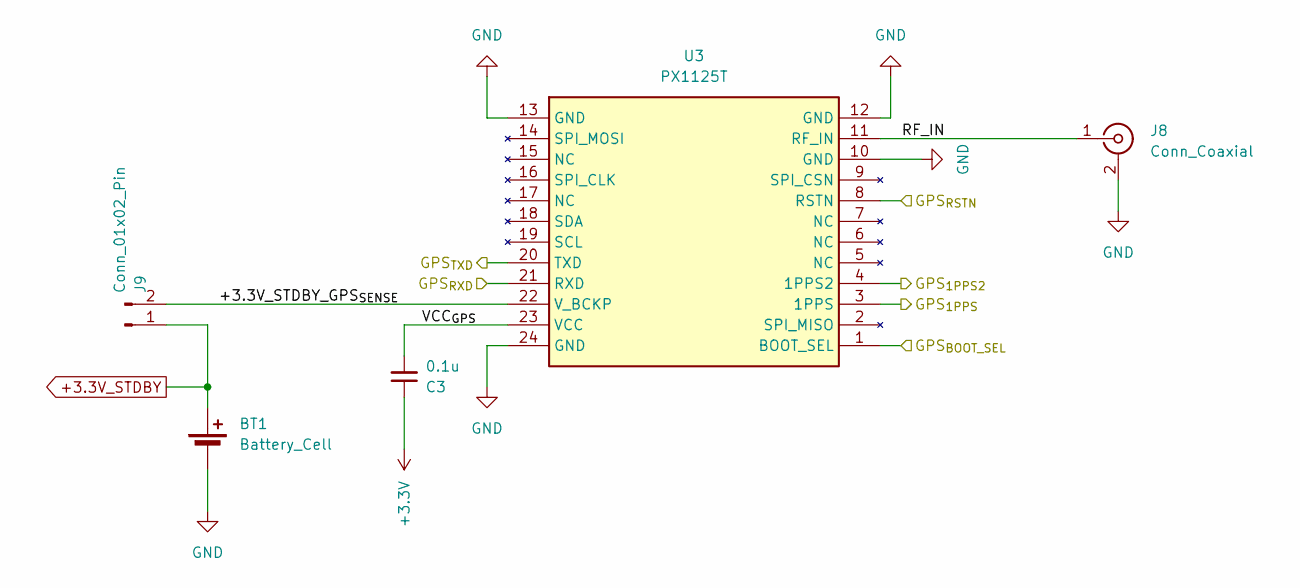
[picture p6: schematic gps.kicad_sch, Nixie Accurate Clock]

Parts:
BT1: Battery_Cell; BatteryHolder_Keystone_3002_1x2032
C3: 0.1u; C_0603_1608Metric
J8: Conn_Coaxial; SMA_Amphenol_132289_EdgeMount
J9: Conn_01x02_Pin; PinHeader_1x02_P2.54mm_Vertical_SMD_Pin1Right
U3: PX1125T; Digikey link N/A

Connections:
+3.3V: C3.1; also elsewhere on the board
+3.3V_STDBY: BT1.1 (+), J9.1; also elsewhere on the board
/GPS/+3.3V_STDBY_GPS_{SENSE}: J9.2, U3.22 (V_BCKP)
/GPS/GPS_{1PPS2}: U3.4 (1PPS2); also elsewhere on the board
/GPS/GPS_{1PPS}: U3.3 (1PPS); also elsewhere on the board
/GPS/GPS_{BOOT_SEL}: U3.1 (BOOT_SEL); also elsewhere on the board
/GPS/GPS_{RSTN}: U3.8 (RSTN); also elsewhere on the board
/GPS/GPS_{RXD}: U3.21 (RXD); also elsewhere on the board
/GPS/GPS_{TXD}: U3.20 (TXD); also elsewhere on the board
/GPS/RF_IN: J8.1 (In), U3.11 (RF_IN)
/GPS/VCC_{GPS}: C3.2, U3.23 (VCC)
GND: BT1.2 (-), J8.2 (Ext), U3.10 (GND), U3.12 (GND), U3.13 (GND), U3.24 (GND); also elsewhere on the board

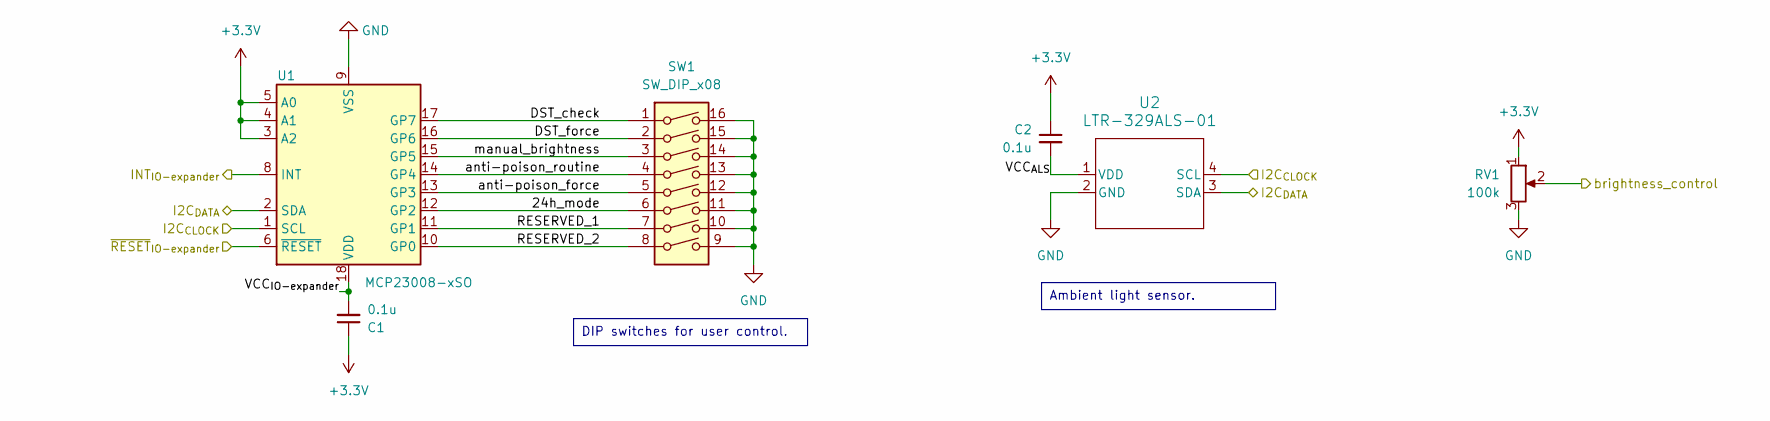
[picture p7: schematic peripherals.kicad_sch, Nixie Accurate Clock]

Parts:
C1, C2: 0.1u; C_0603_1608Metric
RV1: 100k; Potentiometer_Bourns_3269X_Horizontal
SW1: SW_DIP_x08; SW_DIP_SPSTx08_Slide_6.7x21.88mm_W8.61mm_P2.54mm_LowProfile
U1: MCP23008-xSO; SOIC-18W_7.5x11.6mm_P1.27mm
U2: LTR-329ALS-01; LTR-329ALS-01_LTO

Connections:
+3.3V: C1.1, C2.1, RV1.1, U1.3 (A2), U1.4 (A1), U1.5 (A0); also elsewhere on the board
/Peripherals/24h_mode: SW1.6, U1.12 (GP2)
/Peripherals/DST_check: SW1.1, U1.17 (GP7)
/Peripherals/DST_force: SW1.2, U1.16 (GP6)
/Peripherals/I2C_{CLOCK}: U1.1 (SCL), U2.4 (SCL); also elsewhere on the board
/Peripherals/I2C_{DATA}: U1.2 (SDA), U2.3 (SDA); also elsewhere on the board
/Peripherals/INT_{IO-expander}: U1.8 (INT); also elsewhere on the board
/Peripherals/RESERVED_1: SW1.7, U1.11 (GP1)
/Peripherals/RESERVED_2: SW1.8, U1.10 (GP0)
/Peripherals/VCC_{ALS}: C2.2, U2.1 (VDD)
/Peripherals/VCC_{IO-expander}: C1.2, U1.18 (VDD)
/Peripherals/anti-poison_force: SW1.5, U1.13 (GP3)
/Peripherals/anti-poison_routine: SW1.4, U1.14 (GP4)
/Peripherals/brightness_control: RV1.2; also elsewhere on the board
/Peripherals/manual_brightness: SW1.3, U1.15 (GP5)
/Peripherals/~RESET_{IO-expander}: U1.6 (~RESET); also elsewhere on the board
GND: RV1.3, SW1.9, SW1.10, SW1.11, SW1.12, SW1.13, SW1.14, SW1.15, SW1.16, U1.9 (VSS), U2.2 (GND); also elsewhere on the board

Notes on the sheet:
Ambient light sensor.
DIP switches for user control.

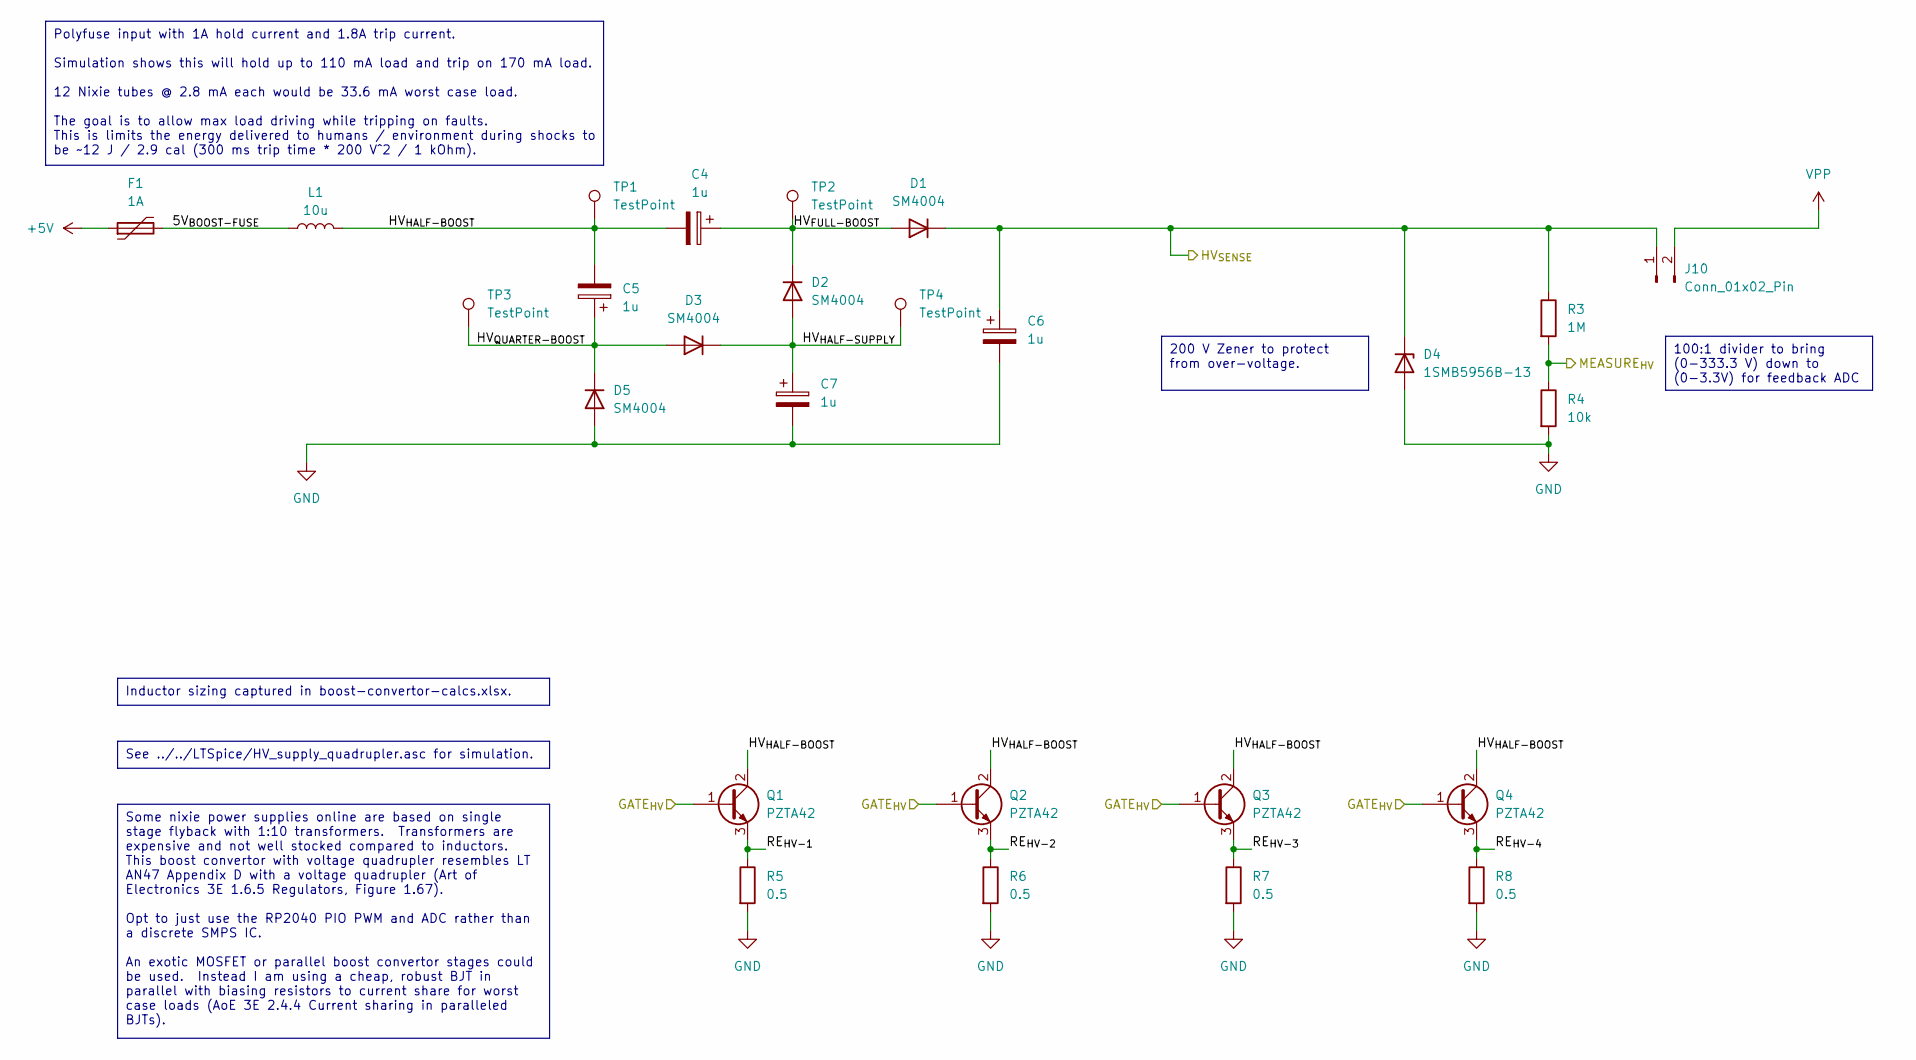
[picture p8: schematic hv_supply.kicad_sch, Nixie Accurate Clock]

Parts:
C4, C5, C6, C7: 1u; CP_Elec_8x10
D1, D2, D3, D5: SM4004; D_MELF
D4: 1SMB5956B-13; D_SMB
F1: 1A; Fuse_1206_3216Metric
J10: Conn_01x02_Pin; PinHeader_1x02_P2.54mm_Vertical_SMD_Pin1Right
L1: 10u; IND_BOURNS_SRR1280
Q1, Q2, Q3, Q4: PZTA42; SOT-223-3_TabPin2
R3: 1M; R_0603_1608Metric
R4: 10k; R_0603_1608Metric
R5, R6, R7, R8: 0.5; R_2010_5025Metric
TP1, TP2, TP3, TP4: TestPoint; TestPoint_Keystone_5019_Minature

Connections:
+5V: F1.1; also elsewhere on the board
/HV bleed/HV_{SENSE}: C6.1, D1.1 (K), D4.1 (K), J10.1, R3.1; also elsewhere on the board
/High voltage supply/5V_{BOOST-FUSE}: F1.2, L1.1
/High voltage supply/GATE_{HV}: Q1.1 (B), Q2.1 (B), Q3.1 (B), Q4.1 (B); also elsewhere on the board
/High voltage supply/HV_{FULL-BOOST}: C4.1, D1.2 (A), D2.1 (K), TP2.1
/High voltage supply/HV_{HALF-BOOST}: C4.2, C5.2, L1.2, Q1.2 (C), Q2.2 (C), Q3.2 (C), Q4.2 (C), TP1.1
/High voltage supply/HV_{HALF-SUPPLY}: C7.1, D2.2 (A), D3.1 (K), TP4.1
/High voltage supply/HV_{QUARTER-BOOST}: C5.1, D3.2 (A), D5.1 (K), TP3.1
/High voltage supply/MEASURE_{HV}: R3.2, R4.1; also elsewhere on the board
/High voltage supply/RE_{HV-1}: Q1.3 (E), R5.1
/High voltage supply/RE_{HV-2}: Q2.3 (E), R6.1
/High voltage supply/RE_{HV-3}: Q3.3 (E), R7.1
/High voltage supply/RE_{HV-4}: Q4.3 (E), R8.1
GND: C6.2, C7.2, D4.2 (A), D5.2 (A), R4.2, R5.2, R6.2, R7.2, R8.2; also elsewhere on the board
VPP: J10.2; also elsewhere on the board

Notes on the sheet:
Polyfuse input with 1A hold current and 1.8A trip current. Simulation shows this will hold up to 110 mA load and trip on 170 mA load. 12 Nixie tubes @ 2.8 mA each would be 33.6 mA worst case load. The goal is to allow max load driving while tripping on faults. This is limits the energy delivered to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
100:1 divider to bring (0-333.3 V) down to (0-3.3V) for feedback ADC
Inductor sizing captured in boost-convertor-calcs.xlsx.
200 V Zener to protect from over-voltage.
See ../../LTSpice/HV_supply_quadrupler.asc for simulation.
Some nixie power supplies online are based on single stage flyback with 1:10 transformers. Transformers are expensive and not well stocked compared to inductors. This boost convertor with voltage quadrupler resembles LT AN47 Appendix D with a voltage quadrupler (Art of Electronics 3E 1.6.5 Regulato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

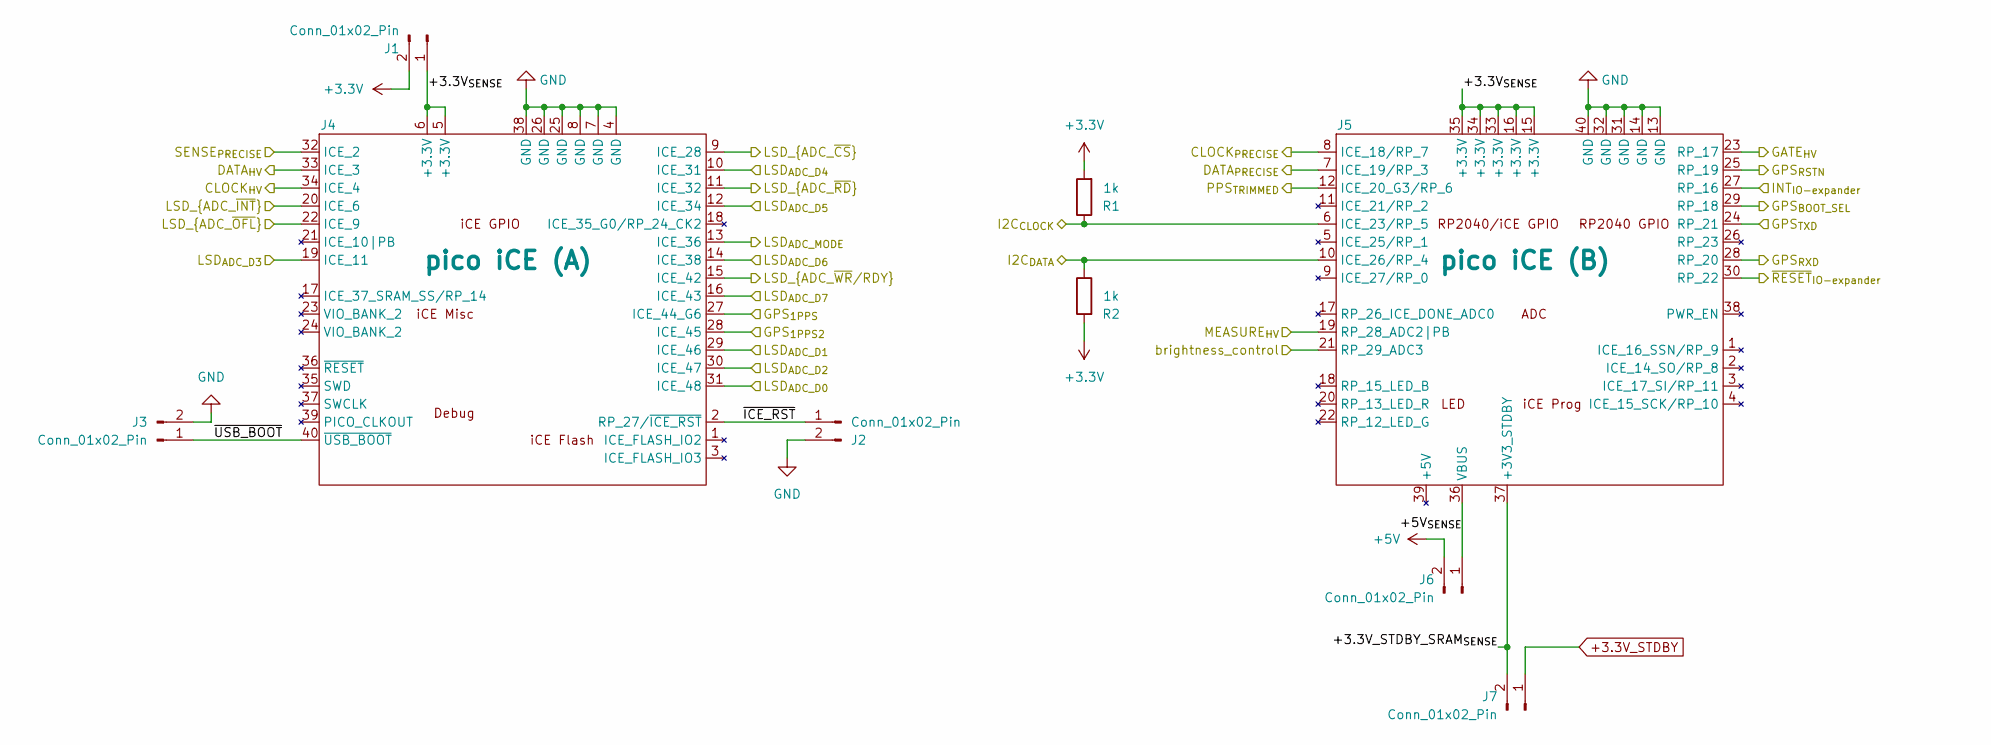
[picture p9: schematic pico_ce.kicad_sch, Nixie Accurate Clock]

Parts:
J1, J2, J3, J6, J7: Conn_01x02_Pin; PinHeader_1x02_P2.54mm_Vertical_SMD_Pin1Right
J4: pico iCE (A)
J5: pico iCE (B)
R1, R2: 1k; R_0603_1608Metric

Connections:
+3.3V: J1.2, R1.2, R2.2; also elsewhere on the board
+3.3V_STDBY: J7.1; also elsewhere on the board
+5V: J6.2; also elsewhere on the board
/GPS/GPS_{1PPS2}: J4.28 (ICE_45); also elsewhere on the board
/GPS/GPS_{1PPS}: J4.27 (ICE_44_G6); also elsewhere on the board
/GPS/GPS_{BOOT_SEL}: J5.29 (RP_18); also elsewhere on the board
/GPS/GPS_{RSTN}: J5.25 (RP_19); also elsewhere on the board
/GPS/GPS_{RXD}: J5.28 (RP_20); also elsewhere on the board
/GPS/GPS_{TXD}: J5.24 (RP_21); also elsewhere on the board
/High voltage supply/GATE_{HV}: J5.23 (RP_17); also elsewhere on the board
/High voltage supply/MEASURE_{HV}: J5.19 (RP_28_ADC2|PB); also elsewhere on the board
/LSD ADC/LSD_{ADC_D0}: J4.31 (ICE_48); also elsewhere on the board
/LSD ADC/LSD_{ADC_D1}: J4.29 (ICE_46); also elsewhere on the board
/LSD ADC/LSD_{ADC_D2}: J4.30 (ICE_47); also elsewhere on the board
/LSD ADC/LSD_{ADC_D3}: J4.19 (ICE_11); also elsewhere on the board
/LSD ADC/LSD_{ADC_D4}: J4.10 (ICE_31); also elsewhere on the board
/LSD ADC/LSD_{ADC_D5}: J4.12 (ICE_34); also elsewhere on the board
/LSD ADC/LSD_{ADC_D6}: J4.14 (ICE_38); also elsewhere on the board
/LSD ADC/LSD_{ADC_D7}: J4.16 (ICE_43); also elsewhere on the board
/LSD ADC/LSD_{ADC_MODE}: J4.13 (ICE_36); also elsewhere on the board
/LSD ADC/LSD_{ADC_~CS}: J4.9 (ICE_28); also elsewhere on the board
/LSD ADC/LSD_{ADC_~INT}: J4.20 (ICE_6); also elsewhere on the board
/LSD ADC/LSD_{ADC_~OFL}: J4.22 (ICE_9); also elsewhere on the board
/LSD ADC/LSD_{ADC_~RD}: J4.11 (ICE_32); also elsewhere on the board
/LSD ADC/LSD_{ADC_~WR/RDY}: J4.15 (ICE_42); also elsewhere on the board
/Nixies/CLOCK_{HV}: J4.34 (ICE_4); also elsewhere on the board
/Nixies/CLOCK_{PRECISE}: J5.8 (ICE_18/RP_7); also elsewhere on the board
/Nixies/DATA_{HV}: J4.33 (ICE_3); also elsewhere on the board
/Nixies/DATA_{PRECISE}: J5.7 (ICE_19/RP_3); also elsewhere on the board
/Nixies/PPS_{TRIMMED}: J5.12 (ICE_20_G3/RP_6); also elsewhere on the board
/Nixies/SENSE_{PRECISE}: J4.32 (ICE_2); also elsewhere on the board
/Peripherals/I2C_{CLOCK}: J5.6 (ICE_23/RP_5), R1.1; also elsewhere on the board
/Peripherals/I2C_{DATA}: J5.10 (ICE_26/RP_4), R2.1; also elsewhere on the board
/Peripherals/INT_{IO-expander}: J5.27 (RP_16); also elsewhere on the board
/Peripherals/brightness_control: J5.21 (RP_29_ADC3); also elsewhere on the board
/Peripherals/~RESET_{IO-expander}: J5.30 (RP_22); also elsewhere on the board
/Pico Ice/+3.3V_STDBY_SRAM_{SENSE}: J5.37 (+3V3_STDBY), J7.2
/Pico Ice/+3.3V_{SENSE}: J1.1, J4.5 (+3.3V), J4.6 (+3.3V), J5.15 (+3.3V), J5.16 (+3.3V), J5.33 (+3.3V), J5.34 (+3.3V), J5.35 (+3.3V)
/Pico Ice/+5V_{SENSE}: J5.36 (VBUS), J6.1
/Pico Ice/~ICE_RST: J2.1, J4.2 (RP_27/~ICE_RST)
/Pico Ice/~USB_BOOT: J3.1, J4.40 (~USB_BOOT)
GND: J2.2, J3.2, J4.4 (GND), J4.7 (GND), J4.8 (GND), J4.25 (GND), J4.26 (GND), J4.38 (GND), J5.13 (GND), J5.14 (GND), J5.31 (GND), J5.32 (GND), J5.40 (GND); also elsewhere on the board

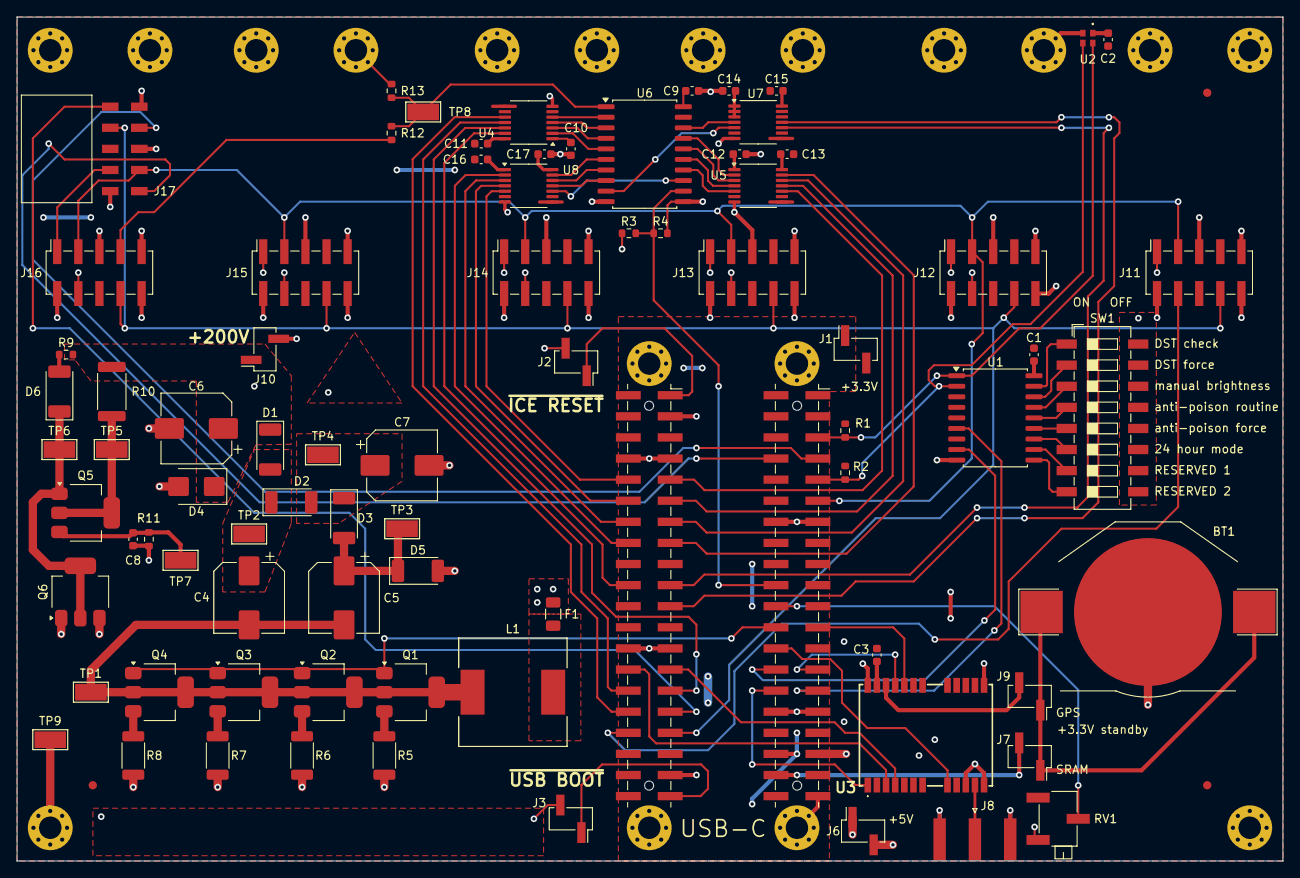
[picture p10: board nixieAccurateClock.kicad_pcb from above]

Board: 4 copper layers, 152.4 x 101.6 mm, 102 parts (0 on the bottom side), 101 nets.

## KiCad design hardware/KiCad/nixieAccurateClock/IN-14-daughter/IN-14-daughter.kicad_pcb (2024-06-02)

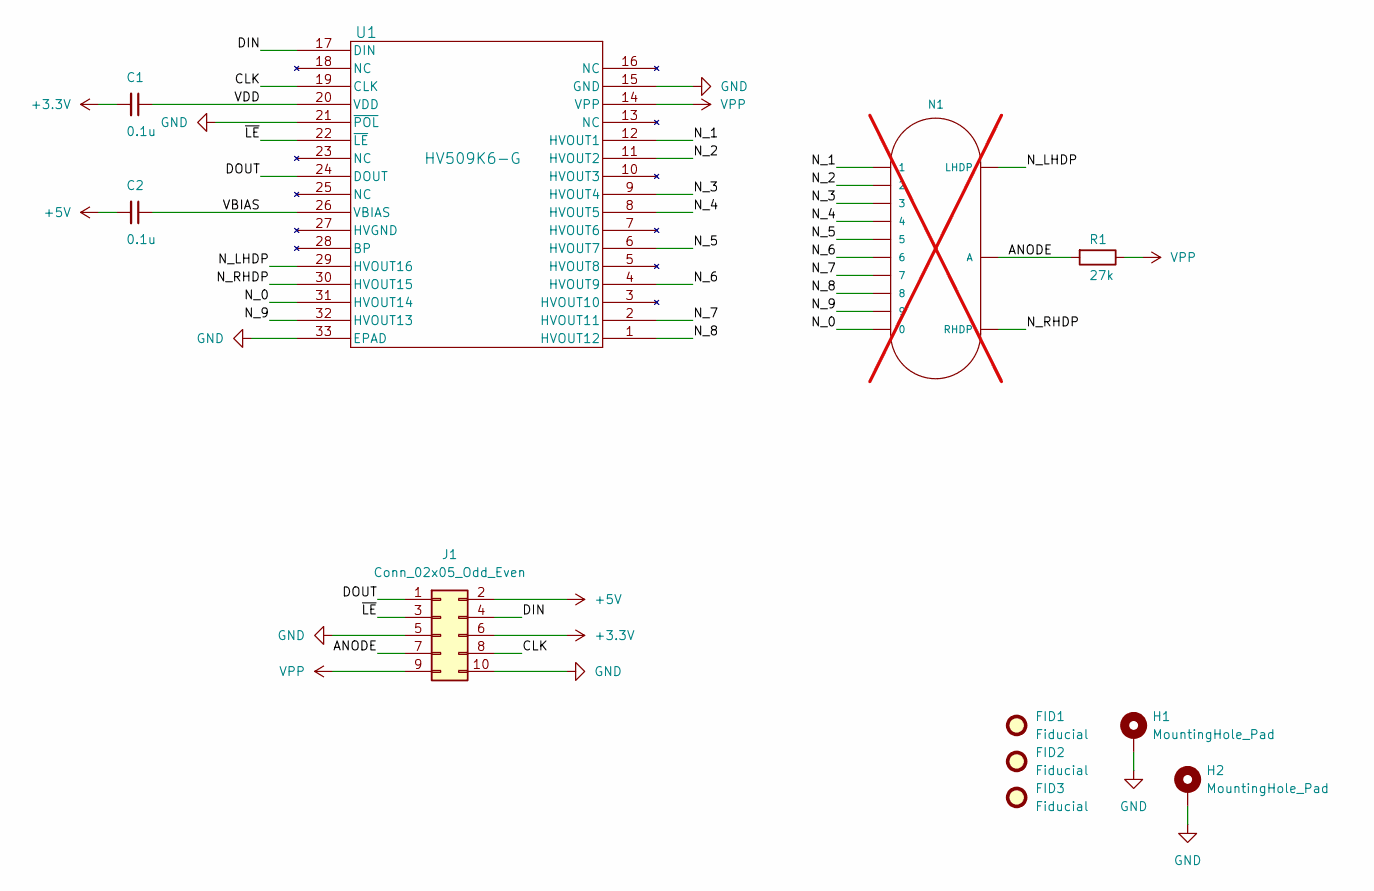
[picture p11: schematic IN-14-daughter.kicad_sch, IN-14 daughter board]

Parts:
C1, C2: 0.1u; C_0603_1608Metric
FID1, FID2, FID3: Fiducial; Fiducial_0.5mm_Mask1.5mm
H1, H2: MountingHole_Pad; MountingHole_2.7mm_M2.5_Pad_Via
J1: Conn_02x05_Odd_Even; PinHeader_2x05_P2.54mm_Vertical_SMD
N1: IN-14; nixies-us-IN-14; Digikey link N/A; not fitted
R1: 27k; R_1206_3216Metric
U1: HV509K6-G; QFN-32-1EP_5x5mm_P0.5mm_EP3.3x3.3mm_ThermalVias

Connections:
+3.3V: C1.2, J1.6
+5V: C2.2, J1.2
/ANODE: J1.7, N1.A, R1.2
/CLK: J1.8, U1.19 (CLK)
/DIN: J1.4, U1.17 (DIN)
/DOUT: J1.1, U1.24 (DOUT)
/N_0: N1.0, U1.31 (HVOUT14)
/N_1: N1.1, U1.12 (HVOUT1)
/N_2: N1.2, U1.11 (HVOUT2)
/N_3: N1.3, U1.9 (HVOUT4)
/N_4: N1.4, U1.8 (HVOUT5)
/N_5: N1.5, U1.6 (HVOUT7)
/N_6: N1.6, U1.4 (HVOUT9)
/N_7: N1.7, U1.2 (HVOUT11)
/N_8: N1.8, U1.1 (HVOUT12)
/N_9: N1.9, U1.32 (HVOUT13)
/N_LHDP: N1.LHDP, U1.29 (HVOUT16)
/N_RHDP: N1.RHDP, U1.30 (HVOUT15)
/VBIAS: C2.1, U1.26 (VBIAS)
/VDD: C1.1, U1.20 (VDD)
/~LE: J1.3, U1.22 (~LE)
GND: H1.1, H2.1, J1.5, J1.10, U1.15 (GND), U1.21 (~POL), U1.33 (EPAD)
VPP: J1.9, R1.1, U1.14 (VPP)

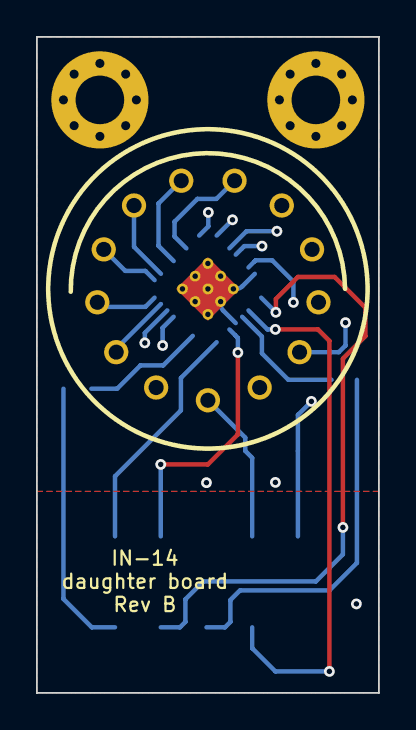
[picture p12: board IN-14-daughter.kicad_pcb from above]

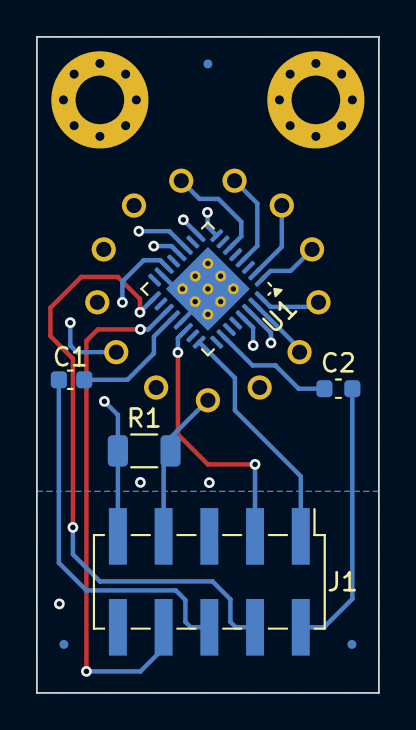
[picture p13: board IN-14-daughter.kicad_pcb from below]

Board: 4 copper layers, 19.0 x 36.4 mm, 11 parts (8 on the bottom side), 23 nets.

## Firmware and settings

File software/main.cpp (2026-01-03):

// pico-sdk
#include "pico/stdlib.h"
#include "pico/stdio.h"
#include "pico/multicore.h"
#include "boards/pico_ice.h"
#include "hardware/irq.h"
#include "hardware/gpio.h"
#include "hardware/uart.h"
#include "hardware/i2c.h"
#include "hardware/adc.h"
#include "hardware/pwm.h"
#include "hardware/pll.h"
#include "hardware/clocks.h"
#include "hardware/structs/pll.h"
#include "hardware/structs/clocks.h"
#include "hardware/watchdog.h"

// pico-ice-sdk
#include "ice_usb.h"
#include "ice_cram.h"
#include "ice_fpga.h"
#include "ice_led.h"
#include "ice_spi.h"

uint8_t bitstream[] = {
#include "bitstream.h"
};

// pin definitions

#define UART_TX_PIN 0
#define UART_RX_PIN 1

#define I2C i2c0
#define I2C_SDA_PIN 4
#define I2C_SCL_PIN 5
#define UART_GPS_RSTN_PIN 19
#define UART_GPS_TX_PIN 20
#define UART_GPS_RX_PIN 21
#define HV_CONTROL_PIN 17
#define HV_MEASURE_PIN 28
#define BRIGHTNESS_CONTROL_PIN 29
#define INT_IO_EXPAND_PIN 16
#define RESET_IO_EXPAND_PIN 22

#define FLAG_VALUE 123

#define HV_MIN 145
#define HV_MAX 190
#define HV_CUTOFF 195


// keep track of loop iterations
uint32_t iLoopCounter = 0;
uint32_t iLoopCounterLast = 0;
float tNow = 0.0f;
float tLast = 0.0f;
// ADC temporary input
uint16_t ADC_val;
// ADC inputs
uint16_t HV_ADC_counts;
float HV_measure;
uint16_t brightness_ADC_counts;
float brightness_control;
// HV control values
float HV_target;
float HV_error;
float HV_PWM_set;
uint16_t HV_PWM_high_cycles;

// 12-bit conversion, assume max value == ADC_VREF == 3.3 V
const float ADC_Vref = 3.3f;
const float ADC_conversion_factor = ADC_Vref / (float)((1 << 12) - 1);
// 1/101 voltage divider
const float HV_measure_Rtop = 10000000.0f;
const float HV_measure_Rbot = 100000.0f;
const float HV_conversion_factor = (HV_measure_Rtop + HV_measure_Rbot) / HV_measure_Rbot;
// 0 - 100 %
const float brightness_conversion_factor = 1.0f / ADC_Vref;

// Find out which PWM slice is connected to GPIO 17
const uint8_t HV_drive_slice_num = pwm_gpio_to_slice_num(HV_CONTROL_PIN);
// PWM parameters
const float HV_PWM_freq = 100000.0f;
const uint16_t HV_PWM_cycles = (float)clock_get_hz(clk_sys) / HV_PWM_freq;


bool hv_timer_callback(struct repeating_timer *t) {
    // Read in ADC measuring HV, run control algorithm, and update HV boost PWM output
    
    iLoopCounter++;
    
    // Select ADC input 2, HV_MEASURE
    adc_select_input(2);
    HV_ADC_counts = adc_read();
    HV_measure = HV_ADC_counts * ADC_conversion_factor * HV_conversion_factor;
    
    // Select ADC input 3, brightness_control
    adc_select_input(3);
    brightness_ADC_counts = adc_read();
    brightness_control = brightness_ADC_counts * ADC_conversion_factor * brightness_conversion_factor;
    
    HV_target = HV_MIN + ((HV_MAX - HV_MIN) * brightness_control);
    HV_error = HV_measure - HV_target;
    
    if (HV_measure > 50.0f) {
        // Set duty cycle to 0% when above the cutoff voltage
        HV_PWM_set = 0.0f;
    } else {
        // otherwise run control loop
        HV_PWM_set = 5.0f / 100.0f;
    }
    // update PWM duty cycle
    HV_PWM_high_cycles = HV_PWM_set * (float)HV_PWM_cycles;
    pwm_set_chan_level(HV_drive_slice_num, PWM_CHAN_B, HV_PWM_high_cycles);
    
    // let watchdog know we're still okay
    watchdog_update();
    
    return true;
}


void core1_entry() {
    multicore_fifo_push_blocking(FLAG_VALUE);
    
    uint32_t g = multicore_fifo_pop_blocking();
    
    if (g != FLAG_VALUE) {
        printf("Hmm, that's not right on core 1!\n");
    } else {
        printf("Its all gone well on core 1!");
    }
    
    // set up PWM output
    HV_PWM_set = 0.0f;
    // Set period in sys_clk cycles (0 to N-1 inclusive)
    pwm_set_wrap(HV_drive_slice_num, HV_PWM_cycles - 1);
    // Set channel B duty cycle
    HV_PWM_high_cycles = HV_PWM_set * (float)HV_PWM_cycles;
    pwm_set_chan_level(HV_drive_slice_num, PWM_CHAN_B, HV_PWM_high_cycles);
    // Set the PWM running
    pwm_set_enabled(HV_drive_slice_num, true);
    
    // repeating 1 kHz timer for HV control
    struct repeating_timer hv_timer;
    // 984 us is tuned to hit a 1.000 kHz loop
    add_repeating_timer_us(984, hv_timer_callback, NULL, &hv_timer);
    
    // Enable the watchdog, requiring the watchdog to be updated every 10 ms or the chip will reboot
    // second arg is pause on debug which means the watchdog will pause when stepping through code
    watchdog_enable(10, 1);
    
    while (true) {
        sleep_ms(100);
    }
}


bool print_timer_callback(struct repeating_timer *t) {
    // print out status info
    
    tNow = (float)time_us_64() / 1000000.0f;
    
    // clear terminal contents
    printf("\e[1;1H\e[2J");
    // print updated values
    printf("Repeat at:  %8f\r\n", tNow - tLast);
    printf("Loop Count: %d\r\n", iLoopCounter - iLoopCounterLast);
    printf("HV:         %8.3f V\r\n", HV_measure);
    printf("HV target:  %8.3f V\r\n", HV_target);
    printf("HV error:   %+7.3f V\r\n", HV_error);
    printf("HV DC:      %8.3f %%\r\n", HV_PWM_set * 100.0f);
    printf("HV High:    %5d cycles\r\n", HV_PWM_high_cycles);
    printf("HV Total:   %5d cycles\r\n", HV_PWM_cycles);
    printf("brightness: %9.3f %%\r\n", brightness_control * 100.0f);
    printf("\r\n");
    
    tLast = tNow;
    iLoopCounterLast = iLoopCounter;
    
    return true;
}


int main(void) {
    // Enable USB-CDC #0 (serial console)
    stdio_init_all();

    // configure pins

    // RP2040 I2C
    i2c_init(i2c_default, 400 * 1000);
    gpio_set_function(I2C_SDA_PIN, GPIO_FUNC_I2C);
    gpio_set_function(I2C_SCL_PIN, GPIO_FUNC_I2C);
    gpio_pull_up(I2C_SDA_PIN);
    gpio_pull_up(I2C_SCL_PIN);

    // GPS UART
    uart_init(uart1, 115200);
    gpio_set_function(UART_GPS_TX_PIN, GPIO_FUNC_UART);
    gpio_set_function(UART_GPS_RX_PIN, GPIO_FUNC_UART);

    // ADCs
    adc_init();
    adc_gpio_init(HV_MEASURE_PIN);
    adc_gpio_init(BRIGHTNESS_CONTROL_PIN);

    // PWM output
    gpio_set_function(HV_CONTROL_PIN, GPIO_FUNC_PWM);

    // General Purpose Input/Output
    gpio_init(UART_GPS_RSTN_PIN);
    gpio_set_dir(UART_GPS_RSTN_PIN, GPIO_OUT);
    gpio_init(INT_IO_EXPAND_PIN);
    gpio_set_dir(INT_IO_EXPAND_PIN, GPIO_IN);
    gpio_init(RESET_IO_EXPAND_PIN);
    gpio_set_dir(RESET_IO_EXPAND_PIN, GPIO_OUT);

    // Enable the physical UART
    uart_init(uart0, 115200);
    gpio_set_function(UART_TX_PIN, GPIO_FUNC_UART);
    gpio_set_function(UART_RX_PIN, GPIO_FUNC_UART);

    // Let the FPGA start
    ice_fpga_init(48);
	ice_led_init();
    ice_fpga_start();

    // Write the whole bitstream to the FPGA CRAM
    ice_cram_open();
    ice_cram_write(bitstream, sizeof(bitstream));
    ice_cram_close();

    // Configure USB as defined in tusb_config.h
    ice_usb_init();
    
    if (watchdog_caused_reboot()) {
        printf("Rebooted by Watchdog!\n");
    } else {
        printf("Clean boot\n");
    }
    
    // repeating 1 Hz timer for serial printout
    struct repeating_timer print_timer;
    add_repeating_timer_ms(100, print_timer_callback, NULL, &print_timer);
    
    // launch HV control thread
    multicore_launch_core1(core1_entry);
    // Wait for it to start up
    uint32_t g = multicore_fifo_pop_blocking();
 
    if (g != FLAG_VALUE) {
        printf("Hmm, that's not right on core 0!\n");
    } else {
        multicore_fifo_push_blocking(FLAG_VALUE);
        printf("It's all gone well on core 0!");
    }
    
    while (true) {
        tud_task();
        
        sleep_ms(100);
    }
    return 0;
}

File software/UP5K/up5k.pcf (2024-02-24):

set_io clock 35
set_frequency clock 48

set_io --warn-no-port led_blue 39
set_io --warn-no-port led_green 40
set_io --warn-no-port led_red 41
set_io --warn-no-port clk 35


set_io --warn-no-port lsd_adc_d0 48
set_io --warn-no-port lsd_adc_d1 46
set_io --warn-no-port lsd_adc_d2 47
set_io --warn-no-port lsd_adc_d3 11
set_io --warn-no-port lsd_adc_d4 31
set_io --warn-no-port lsd_adc_d5 34
set_io --warn-no-port lsd_adc_d6 38
set_io --warn-no-port lsd_adc_d7 43
set_io --warn-no-port lsd_adc_ofl 9
set_io --warn-no-port lsd_adc_cs 28
set_io --warn-no-port lsd_adc_rd 32
set_io --warn-no-port lsd_adc_mode 36
set_io --warn-no-port lsd_adc_int 6
set_io --warn-no-port lsd_adc_wr_rdy 42

set_io --warn-no-port gps_pps2 44
set_io --warn-no-port gps_pps1 45
set_io --warn-no-port sense_precise 2
set_io --warn-no-port data_hv 3
set_io --warn-no-port clock_hv 4

set_io --warn-no-port i2c_clock 23
set_io --warn-no-port clock_precise 19
set_io --warn-no-port data_precise 18
set_io --warn-no-port i2c_data 26
set_io --warn-no-port pps_trimmed 20


# Signals definition (as in the circuit diagram)
set_io -nowarn ICE_2            2
set_io -nowarn ICE_3            3
set_io -nowarn ICE_4            4
set_io -nowarn ICE_6            6
set_io -nowarn ICE_9            9
set_io -nowarn ICE_10           10
set_io -nowarn ICE_11           11
set_io -nowarn ICE_18           18
set_io -nowarn ICE_19           19
set_io -nowarn ICE_20_G3        20
set_io -nowarn ICE_21           21
set_io -nowarn ICE_23           23
set_io -nowarn ICE_25           25
set_io -nowarn ICE_26           26
set_io -nowarn ICE_27           27
set_io -nowarn ICE_28           28
set_io -nowarn ICE_31           31
set_io -nowarn ICE_32           32
set_io -nowarn ICE_34           34
set_io -nowarn ICE_35_G0        35
set_io -nowarn ICE_36           36
set_io -nowarn ICE_38           38
set_io -nowarn ICE_42           42
set_io -nowarn ICE_43           43
set_io -nowarn ICE_44_G6        44
set_io -nowarn ICE_45           45
set_io -nowarn ICE_46           46
set_io -nowarn ICE_47           47
set_io -nowarn ICE_48           48
set_io -nowarn ICE_FLASH_IO2    12
set_io -nowarn ICE_FLASH_IO3    13
set_io -nowarn ICE_PB           10
set_io -nowarn ICE_SO           14
set_io -nowarn ICE_SI           17
set_io -nowarn ICE_SCK          15
set_io -nowarn ICE_SSN          16
set_io -nowarn SRAM_SS          37
set_io -nowarn LED_G            39
set_io -nowarn LED_B            40
set_io -nowarn LED_R            41

# Silicon IO names
set_io -nowarn IOB_6a           2
set_io -nowarn IOB_9b           3
set_io -nowarn IOB_8a           4
set_io -nowarn IOB_13b          6
set_io -nowarn IOB_16a          9
set_io -nowarn IOB_18a          10
set_io -nowarn IOB_20a          11
set_io -nowarn IOB_31b          18
set_io -nowarn IOB_29b          19
set_io -nowarn IOB_25b          20
set_io -nowarn IOT_23b          21
set_io -nowarn IOT_37a          23
set_io -nowarn IOT_36b          25
set_io -nowarn IOT_39a          26
set_io -nowarn IOT_38b          27
set_io -nowarn IOT_41a          28
set_io -nowarn IOT_42b          31
set_io -nowarn IOT_43a          32
set_io -nowarn IOT_44b          34
set_io -nowarn IOT_46b          35
set_io -nowarn IOT_48b          36
set_io -nowarn IOT_50b          38
set_io -nowarn IOT_51a          42
set_io -nowarn IOT_49a          43
set_io -nowarn IOB_3b           44
set_io -nowarn IOB_5b           45
set_io -nowarn IOB_0a           46
set_io -nowarn IOB_2b           47
set_io -nowarn IOB_4a           48
set_io -nowarn IOB_22a          12
set_io -nowarn IOB_24a          13
set_io -nowarn IOB_18a          10
set_io -nowarn IOB_32a          14
set_io -nowarn IOB_33b          17
set_io -nowarn IOB_34a          15
set_io -nowarn IOB_35b          16
set_io -nowarn IOT_45a          37
set_io -nowarn RGB0             39
set_io -nowarn RGB1             40
set_io -nowarn RGB2             41

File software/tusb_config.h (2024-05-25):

/*
 * The MIT License (MIT)
 *
 * Copyright (c) 2019 Ha Thach (tinyusb.org)
 * Copyright (c) 2022 TinyVision.ai Inc.
 *
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
 * THE SOFTWARE IS PROVIDED "AS IS", WITHOUT WARRANTY OF ANY KIND, EXPRESS OR
 * IMPLIED, INCLUDING BUT NOT LIMITED TO THE WARRANTIES OF MERCHANTABILITY,
 * FITNESS FOR A PARTICULAR PURPOSE AND NONINFRINGEMENT. IN NO EVENT SHALL THE
 * AUTHORS OR COPYRIGHT HOLDERS BE LIABLE FOR ANY CLAIM, DAMAGES OR OTHER
 * LIABILITY, WHETHER IN AN ACTION OF CONTRACT, TORT OR OTHERWISE, ARISING FROM,
 * OUT OF OR IN CONNECTION WITH THE SOFTWARE OR THE USE OR OTHER DEALINGS IN
 * THE SOFTWARE.
 */
#pragma once

// pico-ice-sdk
#include "boards/pico_ice.h"
#include "ice_flash.h"

// RHPort number used for device can be defined by board.mk, port 0 for pico-ice
#define BOARD_DEVICE_RHPORT_NUM     0

// Device mode with rhport and speed defined by board.mk
#define CFG_TUSB_RHPORT0_MODE       OPT_MODE_DEVICE

// Either full or high speed supported by RP2040
#define BOARD_DEVICE_RHPORT_SPEED   OPT_MODE_FULL_SPEED

// Enable Device stack
#define CFG_TUD_ENABLED             1

// Default is max speed that hardware controller could support with on-chip PHY
#define CFG_TUD_MAX_SPEED           OPT_MODE_FULL_SPEED

// Device classes
#define CFG_TUD_CDC                 2
#define CFG_TUD_MSC                 0
#define CFG_TUD_DFU                 1
#define CFG_TUD_DFU_ALT             2
#define CFG_TUD_HID                 0
#define CFG_TUD_MIDI                0
#define CFG_TUD_VENDOR              0

// Configure forwarding between USB CDC and UART
#define ICE_USB_UART0_CDC           1

// CDC FIFO size of TX and RX and Endpoint buffer size
#define CFG_TUD_CDC_RX_BUFSIZE      512
#define CFG_TUD_CDC_TX_BUFSIZE      512
#define CFG_TUD_CDC_EP_BUFSIZE      512

// MSC Buffer size of Device Mass storage
#define CFG_TUD_MSC_BUFSIZE         ICE_FLASH_SECTOR_SIZE

// Must be a multiple of flash page size
#define CFG_TUD_DFU_XFER_BUFSIZE    256

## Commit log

2023-12-17 PICO-iCE v3 pin headers
    [nixieAccurateClock.kicad_pcb, nixieAccurateClock.kicad_sch]
2023-12-20 Connect pico iCE to GPS module
    [BOM-nixie-v3.xlsx, GPS_Pi_Hat_0_2.step, nixieAccurateClock.kicad_pcb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]
2023-12-21 Switch to discrete GPS module
    Switch from GPS daughter board to direct connection since it is so easy to implement, can save on cost, and is higher performance.
    Get project library stood up.
    Add proper mounting holes for pico ice and group components together.
    [GPS_Pi_Hat_0_2.step, nixieAccurateClock.kicad_pcb, nixieAccurateClock.kicad_sch]
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2023-12-23 finish GPS module power and I/O
    [nixieAccurateClock.kicad_pcb, nixieAccurateClock.kicad_sch]
2023-12-23 Add USB-C model and silkscreen for installation aid
    [nixieAccurateClock.kicad_pcb]
2023-12-23 Add high voltage supply
    [boost-convertor-calcs.xlsx, nixieAccurateClock.kicad_pcb, nixieAccurateClock.kicad_sch]
2023-12-23 Add DST controlling DIP switches
    [nixieAccurateClock.kicad_pcb, nixieAccurateClock.kicad_sch]
2023-12-23 add description of DST dipswitches on silk screen
    [nixieAccurateClock.kicad_pcb]
2023-12-24 work on rules pass
    [hv_supply.kicad_sch, hv_supply.kicad_sch.kicad_sch, nixieAccurateClock.kicad_sch]
2023-12-24 proper ERC and DRC pass
    [gps.kicad_sch, hv_supply.kicad_sch, nixieAccurateClock.kicad_pcb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]
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2023-12-27 WIP final feature push
    [IN-14-daughter.kicad_pcb, gps.kicad_sch, hv_supply.kicad_sch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]
2023-12-28 clean up placement and pin assignment
    [gps.kicad_sch, nixieAccurateClock.kicad_pcb, nixieAccurateClock.kicad_sch]
2023-12-28 reroute daughter board
    Swapped standoffs and pin header orientation on IN-14 daughter board so that standoffs face outward. This allows using the daughter board mounting for the mother board mounting.
    [IN-14-daughter.kicad_pcb, IN-14-daughter.kicad_sch, nixieAccurateClock.kicad_pcb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]
2023-12-28 fix daughter board HV compat
    Increase copper weight on IN-14 daughter board to PCBWay's 4 layer 2 oz outer / 1.5 oz inner stackup. This has a 0.22 mm prepreg rather than 0.11 mm prepreg, which helps maintain 200 V clearance (0.2 mm inner, 0.4 mm outer)
    [IN-14-daughter.kicad_pcb]
2023-12-28 simplify nixie daughter board
    Remove cathode pins that would not be usable for current sensing anyway.
    Pivot to using anode pin as shunt measurement with a R2R flash ADC (not yet implemented).
    [IN-14-daughter.kicad_pcb, IN-14-daughter.kicad_sch, boost-convertor-calcs.xlsx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]
2023-12-29 Signal condition shunt signal
    Textbook reference and LTSpice simulation for receipts.
    I attempted a differential amplifier based solution but I failed to get it to work. If it did work it would require more components and likely give little additional benefit.
    ADC implementation WIP.
    [LSD_ADC.kicad_sch, gps.kicad_sch, hv_supply.kicad_sch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]
2023-12-29 fix clearance rules on daughter board
    0.4 mm clearance is not possible to obey with an HV driver IC package that has 0.25 mm pad spacing, but all HV lines can be kept at least 0.25 mm away from everything else and inner layers can be preferentially used.
    WIP ADC interface, logic level convertor has been chosen.
    [IN-14-daughter.kicad_pcb, IN-14-daughter.kicad_sch, LSD_ADC.kicad_sch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]
2023-12-30 DRC pass except ADC
    [LSD_ADC.kicad_sch, gps.kicad_sch, hv_supply.kicad_sch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]
2023-12-30 give pico iCE better mounting
    [LSD_ADC.kicad_sch, gps.kicad_sch, hv_supply.kicad_sch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]
2023-12-30 ERC and DRC pass
    [IN-14-daughter.kicad_pcb, LSD_ADC.kicad_sch, nixieAccurateClock.kicad_pcb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]
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2023-12-31 clean up decoupling caps
    [IN-14-daughter.kicad_pcb, nixieAccurateClock.kicad_pcb]
2023-12-31 WIP HV supply simulation
    [LSD_ADC.kicad_sch, boost-convertor-calcs.xlsx, gps.kicad_sch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]
2023-12-31 fix sims
    SPICE asy files had improper netlist orders for their models
    FIxing this reveals that the LSD ADC circuit needed resistor tweaks, but now behaves much better (~70% of FS range for a 145 V nixie).
    The HV supply still does not sim properly. Will investigate a dedicated driver IC.
    [LSD_ADC.kicad_sch, boost-convertor-calcs.xlsx, hv_supply.kicad_sch]
2023-12-31 Switch to <6 mil package for level shifting
    [LSD_ADC.kicad_sch, gps.kicad_sch, hv_supply.kicad_sch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]
2023-12-31 add delay resistor to level shifter OE
    Resistor is shown on TX0108 data sheet.
    Likely helps slow OE with capacitive input to help with power-on sequencing.
    [LSD_ADC.kicad_sch, gps.kicad_sch, hv_supply.kicad_sch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]
2023-12-31 tie level shift OE to ground
    OE on the TX0108 is internally tied high and should be softly pulled low for power-on sequencing.
    [LSD_ADC.kicad_sch, hv_supply.kicad_sch, nixieAccurateClock.kicad_pcb]
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2024-01-06 simulate HV supply concept
    LM5156 simulation is infeasible
    LTSpice model demonstrating that a two stage buck from 5 to 210 is possible. Both stages run away, but the LM5156 should provide feedback to keep it on target.
    [20V_supply.kicad_sch, LM5155_56_Quickstart_Calculator_for_Boost_Converter_Design_V1_1_1-20to210.xlsx, LM5155_56_Quickstart_Calculator_for_Boost_Converter_Desig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]
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2024-01-08 ERC pass
    layout WIP
    All components arranged except power supplies.
    Most nets routed (all except power supplies and ADC lines).
    [daughter-board-placement.xlsx, nixieAccurateClock.kicad_pcb, nixieAccurateClock.kicad_sch]
2024-01-08 tear it apart again
    I didn't fix the pico iCE pinout after flipping it over.
    I still haven't, but routing is now a fresh start.
    [nixieAccurateClock.kicad_pcb]
2024-01-08 fix pico iCE pinout
    Once and for all
    [nixieAccurateClock.kicad_pcb]
2024-01-11 ERC pass
    Close look at pico iCE pinout
    Add light sensor
    Rough layout for non-HV
    [20V_supply.kicad_sch, HV_bleed.kicad_sch, LSD_ADC.kicad_sch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]
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2024-01-13 add pin assignments
    Pin assignment spreadsheet added
    IN-14 daughter board traces smoothed
    [IN-14-daughter.kicad_pcb, hv_supply.kicad_sch, nixieAccurateClock.kicad_pcb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]
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2024-01-14 swap bleed resistor for SMD
    [BOM-nixieAccurateClock.xlsx, HV_bleed.kicad_sch, nixieAccurateClock.kicad_pcb]
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2024-01-15 switch to 27k R_anode
    Add voltage rail jumpers for different 5V and 3.3V standby applications
    [20V_supply.kicad_sch, BOM-nixieAccurateClock.xlsx, IN-14-daughter.kicad_pcb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]
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2024-01-20 change I2C pins
    Avoid conflict with RP2040/iCE UART
    [nixieAccurateClock-rounded.kicad_pcb, nixieAccurateClock.kicad_pcb, nixieAccurateClock.kicad_sch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]
2024-01-21 initial FPGA software
    Blink LED
    Move folders around in repo for new paradigm
    [20V_supply.kicad_sch, BOM-nixieAccurateClock.xlsx, HV_bleed.kicad_sch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]
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2024-01-27 switch all components to SMT
    layout is a mess
    [20V_supply.kicad_sch, daughter-board-placement.xlsx, gps.kicad_sch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]
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2024-02-14 HV overhaul
    Parallel single stage boost convertor
    Need to find replacement MOSFET because SiB452BK footprint is too small for reasonable manufacturing and HV clearance.
    [20V_supply.kicad_sch, BOM-nixieAccurateClock.xlsx, Boost_quad.kicad_sch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]
2024-02-14 single stage HV supply
    Also switch to a MOSFET with a reasonable footprint
    [Boost_quad.kicad_sch, HV_bleed.kicad_sch, LSD_ADC.kicad_sch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]
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2024-03-09 fix TP1 silk screen
    [HV_bleed.kicad_sch, LSD_ADC.kicad_sch, gps.kicad_sch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]
2024-03-23 Clean up clearances
    Set board clearances, add dimension annotations, clean up pour dimensions
    [HV_bleed.kicad_sch, IN-14-daughter-rounded.kicad_pcb, IN-14-daughter.kicad_pcb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]
2024-03-24 Switch to 2.4 mm stackup
    PCBWAY001 is cheaper than PCBWAY209 (2 oz copper) for 0.2 mm prepreg (200 V clearance)
    [IN-14-daughter-rounded.kicad_pcb, IN-14-daughter.kicad_pcb, nixieAccurateClock-rounded.kicad_pcb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]
2024-03-24 Switch to stackup PCBWAY206
    2.4 mm board is incompatible with SMA connector
    Clean up outdated board notes
    [HV_bleed.kicad_sch, IN-14-daughter-rounded.kicad_pcb, IN-14-daughter.kicad_pcb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]
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2024-04-19 fix 2x1 SM header chirality
    [gps.kicad_sch, hv_supply.kicad_sch, nixieAccurateClock-rounded.kicad_pcb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]
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2024-06-02 more detailed build notes, drop HV divider by 10x
    [HV_bleed.kicad_sch, IN-14-daughter-rounded.kicad_pcb, IN-14-daughter.kicad_pcb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]
2026-01-03 Modify HV supply to attempt to solve weak IC
    [HV_bleed.kicad_sch, LSD_ADC.kicad_sch, gps.kicad_sch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]
